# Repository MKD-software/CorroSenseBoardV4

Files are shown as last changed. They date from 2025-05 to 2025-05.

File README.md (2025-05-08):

# CorroSenseBoardV4

This repository contains documentation, Altium design files, and software for the **CorroSenseBoardV4**.

## Jumpers on PCB

Several jumpers must be configured correctly for the board to function as intended. The jumpers are explained below, grouped by the board type.

---

### Motherboard

#### Power Source Configuration

- **P400 (Pin 2 ↔ Pin 3):**  
  Selects the power source as **internal (USB/BAT)** instead of **energy harvesting**.

- **P401 (Pin 1 ↔ Pin 2):**  
  Selects the **battery** as the power source instead of **USB**.

- **P402 (Pin 2 ↔ Pin 3):**  
  Selects the power source as **internal (USB/BAT)** instead of **energy harvesting**.

#### Signal Routing

- **P105 (Pin 1 ↔ Pin 2):**  
  Routes the **DDS signal** to **P104**, the PZT connector on the motherboard.

- **P106 (Pin 1 ↔ Pin 2):**  
  Sends the **PZT output** to the **TIA** on the motherboard.

- **P107:**  
  *(Function not yet documented)*

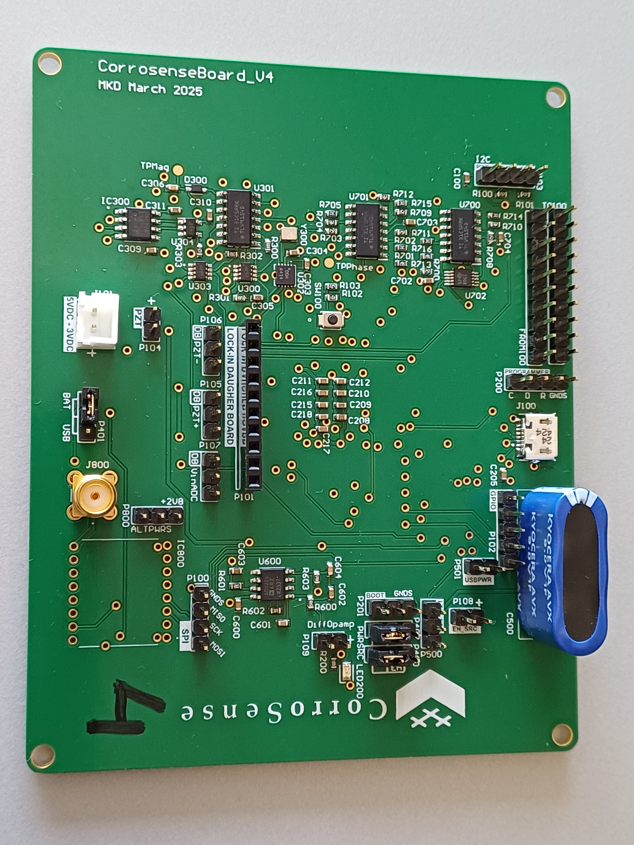
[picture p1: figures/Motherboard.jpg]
Motherboard


---

The board can then be powered on J101 with max 5VDC and min 3VDC.

### Daughterboard

*(Add relevant jumper details here if available)*

## Issues and TODO

#### Motherboard

- The very first ADC reading is always maximum value, doing 1 reading before main loop (and not saving the data) solves the issue.

- Mag and phase measure measurements are identical.

- The DDS gain is highly frequency dependent, above 100kHz the sinewave becomes more like a saw and amplitude of signal decreases. This happens ... could be because of OPAMPS or digital pot.

- Calculate phase and mag, find the right formula, struggling to get correct results, could be due to the VCOMM of 1.4V instead of 0.

- A good measurement is highly dependent on TIA gain and frequency... how to automate it? Maybe make a measurement on the TIA over frequency..?

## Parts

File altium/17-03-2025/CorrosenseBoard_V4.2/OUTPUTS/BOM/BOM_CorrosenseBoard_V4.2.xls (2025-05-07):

 | Component list |  | Bill of Materials for PCB Document [CorrosenseBoardV4_3.PcbDoc]
 | Source Data From: |  | CorrosenseBoardV4_3.PcbDoc
 | Project: |  | CorrosenseBoard_V4.2.PrjPcb
 | Variant: |  | None
 | Report Date: | 17.03.2025 | 10:52
 | Print Date: | 2025-03-17 | 13:52:47
# | Designator | LibRef | Manufacturer | Description | Footprint | MPN | Comment | Quantity
1 | C100 | Cap | Murata Electronics | CAP CER 25V X7R 0603 | 1608[0603] | GCM188R71E224KA55D | 0.22uF | 1
2 | C200, C205, C206, C209, C210, C211, C212, C213, C214, C215, C300, C302, C304, C307, C308, C310, C311, C406, C407, C600, C702, C703, C704, C801 | Cap | Murata Electronics | CAP CER 25V X7R 0603 | 1608[0603] | GCJ188R71E104KA12D | 100nF | 24
3 | C201, C202, C203, C204 | Cap | KYOCERA AVX | CAP CER 25V X7R 0603 | 1608[0603] | 06035A4R3CAT2A | 4.3pF | 4
4 | C207, C216, C217, C400, C403, C504, C505, C506, C507 | Cap | Murata Electronics | CAP CER 25V X7R 0603 | 1608[0603] | GCM188R71E105KA64D | 1uF | 9
5 | C208, C502, C800 | Cap | Murata Electronics | CAP CER 25V X7R 0603 | 1608[0603] | GRM188R61E475KE11J | 4.7uF | 3
6 | C218, C303, C309, C405, C602, C700 | Cap | Murata Electronics | CAP CER 25V X7R 0603 | 1608[0603] | GCJ188R71E103KA01J | 10nF | 6
7 | C301 | Cap | Vishay / Sprague | CAP CER 25V X7R 0603 | 1608[0603] | TR8M106M010C2000 | 10uF Tantalum | 1
8 | C305, C603 | Cap | Murata Electronics | CAP CER 25V X7R 0603 | 1608[0603] | GRM188R71E154KA01D | 150nF | 2
9 | C306, C601, C604 | Cap | KYOCERA AVX | CAP CER 25V X7R 0603 | 1608[0603] | 06033C102KAT2A | 1nF | 3
10 | C401, C402, C404 | Cap | Murata Electronics | CAP CER 25V X7R 0603 | 1608[0603] | GRM188R61E106KA73D | 10uF | 3
11 | C500 | SCMR22L105SRBB0 | Kyocera AVX | Capacitor Polarised | SCMR22L105SRBB0 | SCMR22L105SRBB0 | SCMR22L105SRBB0 | 1
12 | C501 | Cap | Murata Electronics | CAP CER 25V X7R 0603 | 1608[0603] | GRM188C61E226ME01J | 22uF | 1
13 | C503 | Cap | Murata Electronics | CAP CER 25V X7R 0603 | 1608[0603] | GCM188R71E474KA64D | 470nF | 1
14 | C701 | Cap | YAGEO | CAP CER 25V X7R 0603 | 1608[0603] | CC0603KRX7R9BB203 | 20nF | 1
15 | D300 | 1N4148WS | Taiwan Semiconductor | Diode | SOD2513X100N | 1N4148WS | 1N4148WS | 1
16 | FB200, FP400 | BLM21AG121SN1D | Murata Electronics | No Description Available | BEADC2012X105N | BLM21AG121SN1D | BLM21AG121SN1D | 2
17 | FROM100, TO100 | Header 10 | Wurth Elektronik | Header, 10-Pin | HDR1X10 | 61301011121 | Header 10 | 2
18 | IC300 | MAX976ESA+ | Analog Devices | Integrated Circuit | SOIC127P600X175-8N | MAX976ESA+ | MAX976ESA+ | 1
19 | IC400 | ADM7154ACPZ-2.8-R7 | Analog Devices | Integrated Circuit | SON50P300X300X80-9N-D | ADM7154ACPZ-2.8-R7 | ADM7154ACPZ-2.8-R7 | 1
20 | IC401 | MAX6037CAUKADJ+T | Analog Devices | Integrated Circuit | SOT95P280X145-5N | MAX6037CAUKADJ+T | MAX6037CAUKADJ+T | 1
21 | IC500 | EM8500-A001-LF24B | EM Microelectronic-Marin | No Description Available | QFN24_4X4_MAR | EM8500-A001-LF24B+ | EM8500-A001-LF24B | 1
22 | IC800 | RFM98W-433S2 | RF SOLUTIONS | Integrated Circuit | RFM98W433S2 | RFM98W-433S2 | RFM98W-433S2 | 1
23 | J100 | 473460001 | Molex | USB Connectors MICRO USB B RECPT BTTM MOUNT ASSY | Molex_0473460001_0 | 473460001 | 473460001 | 1
24 | J101 | B2B-XH-A | JST Commercial | B2B-XH-A(LF)(SN) | JST_B2B-XH-A | B2B-XH-A(LF)(SN) | B2B-XH-A | 1
25 | J800 | 733910070 | Molex | Connector | 733910070 | 73391-0070 | 733910070 | 1
26 | L500 | Inductor | TAIYO YUDEN | Inductor | C0805 | BRL2012T470M | 47uH | 1
27 | LED200 | 150080RS75000 | Wurth Elektronik | LED | LEDC2012X80N | 150080RS75000 | 150080RS75000 | 1
28 | P100, P103, P200 | Header 4 | Würth Elektronik, Wurth Elektronik | Header, 4-Pin | HDR1X4 | 61300411121 | Header, 4-Pin | 3
29 | P101 | Header 10 | Wurth Elektronik | Header, 10-Pin | HDR1X10 | 61301011821 | Header, 10-Pin FEMALE | 1
30 | P102 | Header 5 | Würth Elektronik | Header, 5-Pin | HDR1X5 | 61300511121 | Header 5 | 1
31 | P104, P108, P109, P501 | Header 2 | Wurth Elektronik | Header, 2-Pin | HDR1X2 | 61300211121 | Header, 2-Pin | 4
32 | P105, P106, P107, P201, P400, P401, P402, P500, P800 | Header 3 | Wurth Elektronik, Mfr.:Wurth Elektronik | Header, 3-Pin | HDR1X3 | 61300311121 | Header, 3-Pin | 9
33 | R100, R101 | Res1 | YAGEO | RES SMD 2% 1.5W 0603, 1608[0603] | 1608[0603] | RC0603FR-072K2L | 2.2K | 2
34 | R102 | Res1 | YAGEO | 1608[0603] | 1608[0603] | AC0603FR-07330RL | 330 | 1
35 | R103 | Res1 | YAGEO | 1608[0603] | 1608[0603] | RC0603FR-07220KL | 220K | 1
36 | R200 | Res1 | YAGEO | 1608[0603] | 1608[0603] | AC0603FR-07150RL | 150 | 1
37 | R201 | Res1 | YAGEO | 1608[0603] | 1608[0603] | RC0603FR-0710RL | 10 | 1
38 | R300, R301 | Res1 | YAGEO | RES SMD 2% 1.5W 0603 | 1608[0603] | AC0603FR-134K99L | 5k | 2
39 | R302, R601 | Res1 | YAGEO | RES SMD 2% 1.5W 0603 | 1608[0603] | RC0603FR-071KL | 1k | 2
40 | R303 | Res1 | YAGEO | RES SMD 2% 1.5W 0603 | 1608[0603] | AC0603FR-1012KL | 12k | 1
41 | R400, R402 | Res1 |  | RES SMD 2% 1.5W 0603 | 1608[0603] |  |  | 2
42 | R401 | Res1 | YAGEO | RES SMD 2% 1.5W 0603 | 1608[0603] | AC0603FR-07150KL | 150k | 1
43 | R403 | Res1 | YAGEO | RES SMD 2% 1.5W 0603 | 1608[0603] | AC0603FR-07820KL | 820k | 1
44 | R600, R603 | Res1 | YAGEO | RES SMD 2% 1.5W 0603 | 1608[0603] | AF0603FR-074K02L | 4.02K | 2
45 | R602 | Res1 | YAGEO | RES SMD 2% 1.5W 0603 | 1608[0603] | AC0603FR-0749K9L | 49.9K | 1
46 | R700, R703, R708, R709, R711 | Res1 | YAGEO | RES SMD 2% 1.5W 0603 | 1608[0603] | AC0603FR-072K4L | 2.4k | 5
47 | R701, R704, R710, R712, R713 | Res1 | YAGEO | RES SMD 2% 1.5W 0603 | 1608[0603] | RC0603FR-075K6L | 5.6k | 5
48 | R702, R705, R707, R714, R715, R716 | Res1 | YAGEO | RES SMD 2% 1.5W 0603 | 1608[0603] | RC0603FR-0710KL | 10k | 6
49 | R706 | Res1 | YAGEO | RES SMD 2% 1.5W 0603 | 1608[0603] | AC0603FR-076K2L | 6.2k | 1
50 | SW100 | B3U-1000P-B | Omron Electronics | No Description Available | B3U-1000P-B | B3U-1000P-B | B3U-1000P-B | 1
51 | U200 | STM32L451VCT6 | STMicroelectronics | No Description Available | LQFP100-14x14mm_STM | STM32L451VCT6 | STM32L451VCT6 | 1
52 | U201 | CP2102-GMR | Silicon Labs | No Description Available | QFN50P500X500X100-29N-D | CP2102-GMR | CP2102-GMR | 1
53 | U300, U303 | TPL0501-100DCNR | Texas Instruments | 256-Taps, 100k, Single-Channel Potentiometer With SPI Interface 8-SOT-23 -40 to 125 | SOT65P280X145-8N | TPL0501-100DCNR | TPL0501-100DCNR | 2
54 | U301, U700, U701 | TLV2444CD | Texas Instruments | No Description Available | SOIC127P600X175-14N | TLV9154IDR | TLV9154IDR | 3
55 | U302 | AD9837ACPZ-RL7 | Analog Devices | No Description Available | CP_10_9_ADI | AD9837BCPZ-RL7 | AD9837BCPZ-RL7 | 1
56 | U304 | SN74AHC1G86DBVR | Texas Instruments | No Description Available | SOT95P280X145-5N | SN74AHC1G86DBVR | SN74AHC1G86DBVR | 1
57 | U600 | AD8226ARZ | Analog Devices Inc | No Description Available | SOIC127P600X175-8N | AD8226ARZ | AD8226ARZ | 1
58 | U702 | ADS1115IDGST | Texas Instruments |  | SOP50P490X110-10N | ADS1115IDGST | ADS1115IDGST | 1
59 | Y200 | ABS07-166-32.768KHZ-T | Abracon LLC | 32.768 kHz Â±10ppm Crystal 7pF 70 kOhms 2-SMD, No Lead | XTAL_ABS07-166-32.768KHZ-T | ABS07-166-32.768KHZ-T | ABS07-166-32.768KHZ-T | 1
60 | Y201 | ABM3-8.000MHZ-D2Y-T | Abracon | No Description Available | XTAL_ABM3-8.000MHZ-D2Y-T | ABM3-8.000MHZ-D2Y-T | ABM3-8.000MHZ-D2Y-T | 1
61 | Y300 | SG-210STF_16.0000ML0 | Epson Timing | Crystal or Oscillator | SG210STF160000ML0 | SG-210STF 16.0000ML0 | SG-210STF_16.0000ML0 | 1
Approved |  |  | Notes |  |  |  |  | 143

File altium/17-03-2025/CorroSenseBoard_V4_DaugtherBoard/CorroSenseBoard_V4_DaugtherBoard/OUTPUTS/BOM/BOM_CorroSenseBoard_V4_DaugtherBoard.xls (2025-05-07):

 | Component list |  | Bill of Materials for BOM Document [CorroSenseBoard_V4_DaugtherBoard.BomDoc]
 | Source Data From: |  | CorroSenseBoard_V4_DaugtherBoard.BomDoc
 | Project: |  | CorroSenseBoard_V4_DaugtherBoard.PrjPcb
 | Variant: |  | None
 | Report Date: | 14.03.2025 | 15:42
 | Print Date: | 2025-03-17 | 13:53:42
# | Designator | LibRef | Manufacturer | Description | Footprint | MPN | Name | Quantity
1 | C200, C300, C301, C302, C318, C319, C320, C321, C322, C323, C324, C325 | Cap | Murata Electronics | CAP CER 25V X7R 0603 | 1608[0603] | GCJ188R71E104KA12D | 100nF | 12
2 | C201 | Cap | KYOCERA AVX | CAP CER 25V X7R 0603 | 1608[0603] | 06033C101KAT2A | 100pF | 1
3 | C202, C204, C303, C305, C309, C311, C313, C317 | Cap | Murata Electronics | CAP CER 25V X7R 0603 | 1608[0603] | GCM188R71E105KA64D | 1uF | 8
4 | C203 | Cap | Murata Electronics | CAP CER 25V X7R 0603 | 1608[0603] | GRM188R61E475KE11J | 4.7uF | 1
5 | C205 | Cap | Murata Electronics | CAP CER 25V X7R 0603 | 1608[0603] | GRM1885C1H4R7WA01D | 4.7pF | 1
6 | C304, C306, C307, C312, C314, C315 | Cap | KYOCERA AVX | CAP CER 25V X7R 0603 | 1608[0603] | 06033C102KAT2A | 1nF | 6
7 | C308, C310, C316 | Cap | Murata Electronics | CAP CER 25V X7R 0603 | 1608[0603] | GRM188R71E154KA01D | 150nF | 3
8 | D200, D201, D202 | ZHCS400TA | Diodes Incorporated | Diode | SOD2513X120N | ZHCS400TA | ZHCS400TA | 3
9 | L200, L201 | Inductor | Murata Electronics | FIXED IND 4.7UH 620MA 550MOHM SM | 6-0805_N | LQM18PN4R7MFRL | LQM18PN4R7MFRL | 2
10 | P100, P102, P200, P201 | Header 2 | Wurth Elektronik | Header, 2-Pin | HDR1X2 | 61300211121 | Header, 2-Pin | 4
11 | P101 | Header 10 | Wurth Elektronik | Header, 10-Pin | HDR1X10 | 61301011121 | Header, 10-Pin | 1
12 | R200 | Res1 | YAGEO | RES SMD 2% 1.5W 0603 | 1608[0603] | AC0603FR-07270KL | 270K | 1
13 | R201 | Res1 | YAGEO | RES SMD 2% 1.5W 0603 | 1608[0603] | RC0603FR-07100KL | 100K | 1
14 | R202 | Res1 | YAGEO | RES SMD 2% 1.5W 0603 | 1608[0603] | AC0603FR-10110KL | 110K | 1
15 | R203 | Res1 | YAGEO | RES SMD 2% 1.5W 0603 | 1608[0603] | AC0603FR-07330KL | 330K | 1
16 | R300 | Res1 | YAGEO | RES SMD 2% 1.5W 0603 | 1608[0603] | RC0603FR-071KL | 1K | 1
17 | R301 | Res1 | YAGEO | RES SMD 2% 1.5W 0603 | 1608[0603] | AC0603FR-072KL | 2K | 1
18 | R302, R304, R305, R308, R309, R310, R314, R316, R317, R320, R321, R322 | Res1 | YAGEO | RES SMD 2% 1.5W 0603 | 1608[0603] | RC0603FR-0710KL | 10K | 12
19 | R303, R311, R313, R315 | Res1 | YAGEO | RES SMD 2% 1.5W 0603 | 1608[0603] | AC0603FR-134K99L | 5k | 4
20 | R306 | Res1 | YAGEO | RES SMD 2% 1.5W 0603 | 1608[0603] | AC0603FR-0762RL | 62 | 1
21 | R307 | Res1 | YAGEO | RES SMD 2% 1.5W 0603 | 1608[0603] | RC0603FR-07470RL | 470 | 1
22 | R312 | Res1 | YAGEO | RES SMD 2% 1.5W 0603 | 1608[0603] | RC0603FR-106K8L | 6.8K | 1
23 | R318 | Res1 | YAGEO | RES SMD 2% 1.5W 0603 | 1608[0603] | RC0603FR-10220RL | 220 | 1
24 | R319 | Res1 | YAGEO | RES SMD 2% 1.5W 0603 | 1608[0603] | RC0603FR-07910RL | 910 | 1
25 | U200 | LT1945EMSPBF | Analog Devices Inc | No Description Available | MSOP-10_MS_LIT | LT1945EMSPBF | LT1945EMSPBF | 1
26 | U300 | MAX5438EUB+ | Analog Devices / Maxim Integrated |  | SOP50P490X110-10N | MAX5438EUB+ | MAX5438EUB+ | 1
27 | U301, U303 | TLV2444CD | Texas Instruments | No Description Available | SOIC127P600X175-14N | TLV9154IDR | TLV9154IDR | 2
28 | U302, U304 | ADI-AD630-RW-20 | Analog Devices | Consumer Circuit, PDSO20 | SOIC127P1032X265-20N | AD630ARZ | AD630ARZ | 2
Approved |  |  | Notes |  |  |  |  | 75

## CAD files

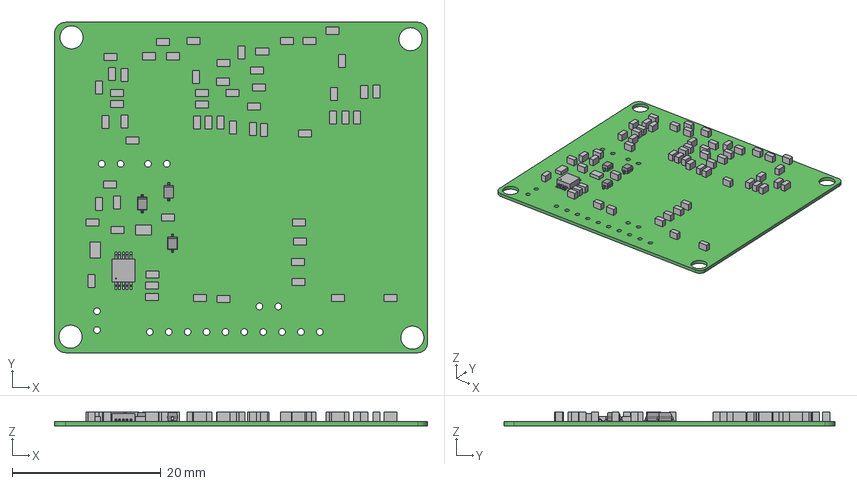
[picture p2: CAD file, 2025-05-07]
altium/17-03-2025/CorroSenseBoard_V4_DaugtherBoard/CorroSenseBoard_V4_DaugtherBoard/OUTPUTS/3D/CorroSenseBoard_V4_DaugtherBoard.step
50.2 x 44.5 x 1.92 mm
Extruded x 61
FilletPinL x 3
FilletPinR x 3

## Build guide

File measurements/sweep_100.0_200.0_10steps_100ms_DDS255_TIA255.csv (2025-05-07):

Frequency [Hz] | Magnitude | Phase [°]
100000 | 0.030518509475997192 | 4212900.0
111111 | 0.04689551678859501 | 2741657.142857143
122222 | 0.03321486697445777 | 3870900.0
133333 | 0.03385125757421888 | 3798128.5714285714
144444 | 0.035143208574942894 | 3658500.0
155555 | 0.03673229503379371 | 3500228.5714285714
166666 | 0.040110705547310575 | 3205414.285714286
177777 | 0.04675081813931744 | 2750142.8571428573
188888 | 0.04594532506317482 | 2798357.1428571427
199999 | 0.04507956543298922 | 2852100.0000000005

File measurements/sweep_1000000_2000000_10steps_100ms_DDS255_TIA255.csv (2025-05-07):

Frequency [Hz] | Magnitude | Phase [°]
100000 | 0.030518509475997192 | 4212900.0
111111 | 0.04688452341881945 | 2742300.0
122222 | 0.03320935175345377 | 3871542.8571428573
133333 | 0.033855841825506994 | 3797614.285714286
144444 | 0.03513950383020592 | 3658885.7142857146
155555 | 0.03672015569346014 | 3501385.7142857146
166666 | 0.04012358062833527 | 3204385.7142857146
177777 | 0.04671587405400355 | 2752200.0000000005
188888 | 0.04595165885488466 | 2797971.4285714286
199999 | 0.04508363013389838 | 2851842.8571428573

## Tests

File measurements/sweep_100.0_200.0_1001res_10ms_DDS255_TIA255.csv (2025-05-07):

Frequency [Hz] | Magnitude | Phase [°]
100000 | 0.030518509475997192 | 4212900.0
100100 | 0.04694394892498357 | 2738828.571428572
100200 | 0.030518509475997192 | 4212900.0
100300 | 0.033627009213800525 | 3823457.142857143
100400 | 0.03341240936883959 | 3848014.2857142864
100500 | 0.03356605800214823 | 3830400.0
100600 | 0.033549166303217366 | 3832328.5714285714
100700 | 0.03352105122016626 | 3835542.8571428577
100800 | 0.0335042047776996 | 3837471.428571429
100900 | 0.03347840642785403 | 3840428.571428572
101001 | 0.033448172057397065 | 3843900.0
101101 | 0.03341910904655282 | 3847242.8571428577
101201 | 0.033399018068868774 | 3849557.1428571427
101301 | 0.03337226764558652 | 3852642.8571428573
101401 | 0.03334444814938313 | 3855857.1428571427
101501 | 0.03332111559094998 | 3858557.142857143
101601 | 0.033297815663292485 | 3861257.142857143
101701 | 0.033276762836511264 | 3863700.0
101801 | 0.03324910227423859 | 3866914.2857142864
101901 | 0.03322479898996611 | 3869742.8571428577
102002 | 0.0332016335203692 | 3872442.8571428573
102102 | 0.03318070210365651 | 3874885.7142857146
102202 | 0.033158697526361164 | 3877457.142857143
102302 | 0.033140016570008285 | 3879642.8571428573
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

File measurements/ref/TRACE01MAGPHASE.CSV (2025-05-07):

!Keysight Technologies | E4990A | MY54302532 | A.03.02
!Date: Wed May 07 10:40:29 2025
BEGIN CH1_DATA
Frequency(Hz) | |Z|(Ohm)-data | theta-z(deg)-data
+5.00000000000e+004 | +1.27921414392e+003 | -8.87571191121e+001
+5.00650250000e+004 | +1.27763299996e+003 | -8.87618906651e+001
+5.01301340000e+004 | +1.27597657355e+003 | -8.87710836920e+001
+5.01953280000e+004 | +1.27412923572e+003 | -8.87730096643e+001
+5.02606070000e+004 | +1.27236761422e+003 | -8.87731828333e+001
+5.03259710000e+004 | +1.27061033431e+003 | -8.87701985494e+001
+5.03914190000e+004 | +1.26886069958e+003 | -8.87635472113e+001
+5.04569530000e+004 | +1.26730949295e+003 | -8.87552114678e+001
+5.05225720000e+004 | +1.26587712046e+003 | -8.87541621611e+001
+5.05882770000e+004 | +1.26437124268e+003 | -8.87657274664e+001
+5.06540670000e+004 | +1.26256444609e+003 | -8.87741318947e+001
+5.07199420000e+004 | +1.26082747170e+003 | -8.87751426842e+001
+5.07859030000e+004 | +1.25911612554e+003 | -8.87757197615e+001
+5.08519500000e+004 | +1.25738101540e+003 | -8.87745714014e+001
+5.09180830000e+004 | +1.25568918543e+003 | -8.87747700130e+001
+5.09843010000e+004 | +1.25394654802e+003 | -8.87742462159e+001
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

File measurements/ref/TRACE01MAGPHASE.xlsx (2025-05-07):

!Keysight Technologies,E4990A,MY54302532,A.03.02
!Date: Wed May 07 10:40:29 2025
BEGIN CH1_DATA
Frequency(Hz), |Z|(Ohm)-data, theta-z(deg)-data
+5.00000000000e+004, +1.27921414392e+003, -8.87571191121e+001
+5.00650250000e+004, +1.27763299996e+003, -8.87618906651e+001
+5.01301340000e+004, +1.27597657355e+003, -8.87710836920e+001
+5.01953280000e+004, +1.27412923572e+003, -8.87730096643e+001
+5.02606070000e+004, +1.27236761422e+003, -8.87731828333e+001
+5.03259710000e+004, +1.27061033431e+003, -8.87701985494e+001
+5.03914190000e+004, +1.26886069958e+003, -8.87635472113e+001
+5.04569530000e+004, +1.26730949295e+003, -8.87552114678e+001
+5.05225720000e+004, +1.26587712046e+003, -8.87541621611e+001
+5.05882770000e+004, +1.26437124268e+003, -8.87657274664e+001
+5.06540670000e+004, +1.26256444609e+003, -8.87741318947e+001
+5.07199420000e+004, +1.26082747170e+003, -8.87751426842e+001
+5.07859030000e+004, +1.25911612554e+003, -8.87757197615e+001
+5.08519500000e+004, +1.25738101540e+003, -8.87745714014e+001
+5.09180830000e+004, +1.25568918543e+003, -8.87747700130e+001
+5.09843010000e+004, +1.25394654802e+003, -8.87742462159e+001
+5.10506060000e+004, +1.25226596191e+003, -8.87737587742e+001
+5.11169970000e+004, +1.25058373141e+003, -8.87719392860e+001
+5.11834750000e+004, +1.24889922433e+003, -8.87711525301e+001
+5.12500390000e+004, +1.24727995219e+003, -8.87688452521e+001
+5.13166890000e+004, +1.24565727264e+003, -8.87661745437e+001
+5.13834260000e+004, +1.24399903517e+003, -8.87687032875e+001
+5.14502500000e+004, +1.24231290944e+003, -8.87691161406e+001
+5.15171610000e+004, +1.24067707529e+003, -8.87686891910e+001
+5.15841590000e+004, +1.23900039417e+003, -8.87681721908e+001
+5.16512440000e+004, +1.23731603456e+003, -8.87687813740e+001
+5.17184160000e+004, +1.23567092807e+003, -8.87663934711e+001
+5.17856760000e+004, +1.23395150941e+003, -8.87630444519e+001
+5.18530230000e+004, +1.23230791823e+003, -8.87600762868e+001
+5.19204570000e+004, +1.23073459956e+003, -8.87523081633e+001
+5.19879800000e+004, +1.22929195935e+003, -8.87516960308e+001
+5.20555900000e+004, +1.22773667616e+003, -8.87568260229e+001
+5.21232880000e+004, +1.22607381168e+003, -8.87606684108e+001
+5.21910740000e+004, +1.22438236107e+003, -8.87601906121e+001
+5.22589480000e+004, +1.22274618103e+003, -8.87615896127e+001
+5.23269110000e+004, +1.22112985040e+003, -8.87607417443e+001
+5.23949620000e+004, +1.21950464679e+003, -8.87606525434e+001
+5.24631010000e+004, +1.21782528927e+003, -8.87602891818e+001
+5.25313290000e+004, +1.21620805296e+003, -8.87606744719e+001
+5.25996460000e+004, +1.21461512804e+003, -8.87589456055e+001
+5.26680520000e+004, +1.21294661325e+003, -8.87580661848e+001
+5.27365460000e+004, +1.21136598932e+003, -8.87564959053e+001
+5.28051300000e+004, +1.20973801214e+003, -8.87577649014e+001
+5.28738030000e+004, +1.20805665922e+003, -8.87570594904e+001
+5.29425650000e+004, +1.20643422705e+003, -8.87556207257e+001
+5.30114170000e+004, +1.20478703389e+003, -8.87501683762e+001
+5.30803580000e+004, +1.20319532915e+003, -8.87464056601e+001
+5.31493890000e+004, +1.20165972320e+003, -8.87425859773e+001
+5.32185090000e+004, +1.20002273805e+003, -8.87376339464e+001
+5.32877200000e+004, +1.19860378310e+003, -8.87308467263e+001
+5.33570200000e+004, +1.19730075346e+003, -8.87346042093e+001
+5.34264110000e+004, +1.19568781425e+003, -8.87480343411e+001
+5.34958910000e+004, +1.19402086902e+003, -8.87532186453e+001
+5.35654630000e+004, +1.19229225238e+003, -8.87548774843e+001
+5.36351240000e+004, +1.19063560002e+003, -8.87530500240e+001
+5.37048770000e+004, +1.18895946756e+003, -8.87503335358e+001
+5.37747200000e+004, +1.18733991957e+003, -8.87464196950e+001
+5.38446530000e+004, +1.18568628288e+003, -8.87432883149e+001
+5.39146780000e+004, +1.18404567301e+003, -8.87415336159e+001
+5.39847940000e+004, +1.18236391996e+003, -8.87327557190e+001
+5.40550010000e+004, +1.18079075784e+003, -8.87196410276e+001
+5.41252990000e+004, +1.17935228496e+003, -8.87041151846e+001
+5.41956890000e+004, +1.17816166274e+003, -8.86979532702e+001
+5.42661700000e+004, +1.17699770241e+003, -8.87011264235e+001
+5.43367430000e+004, +1.17561896980e+003, -8.87208578727e+001
+5.44074080000e+004, +1.17388694355e+003, -8.87314923851e+001
+5.44781640000e+004, +1.17223532219e+003, -8.87308232925e+001
+5.45490130000e+004, +1.17071936042e+003, -8.87302489228e+001
+5.46199540000e+004, +1.16918160194e+003, -8.87386959392e+001
+5.46909870000e+004, +1.16746126411e+003, -8.87448465278e+001
+5.47621120000e+004, +1.16576206784e+003, -8.87415495014e+001
+5.48333300000e+004, +1.16409985003e+003, -8.87408891318e+001
+5.49046410000e+004, +1.16246427902e+003, -8.87377561103e+001
+5.49760440000e+004, +1.16080515369e+003, -8.87352824400e+001
+5.50475400000e+004, +1.15913740112e+003, -8.87271436968e+001
+5.51191290000e+004, +1.15747108560e+003, -8.87156221396e+001
+5.51908110000e+004, +1.15599336118e+003, -8.86965913111e+001
+5.52625870000e+004, +1.15485064618e+003, -8.86805480708e+001
+5.53344560000e+004, +1.15377770370e+003, -8.86808334226e+001
+5.54064180000e+004, +1.15257468677e+003, -8.86988036896e+001
+5.54784740000e+004, +1.15093415832e+003, -8.87215242238e+001
+5.55506230000e+004, +1.14913131130e+003, -8.87253790174e+001
+5.56228660000e+004, +1.14740601341e+003, -8.87241431349e+001
+5.56952040000e+004, +1.14569525897e+003, -8.87178967029e+001
+5.57676350000e+004, +1.14410881501e+003, -8.87040913295e+001
+5.58401610000e+004, +1.14276314075e+003, -8.86928600222e+001
+5.59127810000e+004, +1.14142143384e+003, -8.87000146188e+001
+5.59854950000e+004, +1.13963524959e+003, -8.87028650957e+001
+5.60583040000e+004, +1.13791415946e+003, -8.86836832047e+001
+5.61312070000e+004, +1.13643609826e+003, -8.86525935264e+001
+5.62042060000e+004, +1.13568420264e+003, -8.86225086908e+001
+5.62772990000e+004, +1.13533869222e+003, -8.86399903713e+001
+5.63504880000e+004, +1.13400308268e+003, -8.86899595285e+001
+5.64237710000e+004, +1.13218890711e+003, -8.87110597392e+001
+5.64971500000e+004, +1.13044746819e+003, -8.87152676136e+001
+5.65706240000e+004, +1.12889279426e+003, -8.87179015701e+001
+5.66441940000e+004, +1.12730792104e+003, -8.87231165436e+001
+5.67178600000e+004, +1.12573689201e+003, -8.87253646529e+001
+5.67916210000e+004, +1.12417895343e+003, -8.87275549570e+001
+5.68654780000e+004, +1.12263595984e+003, -8.87287274247e+001
+5.69394320000e+004, +1.12109202967e+003, -8.87319932930e+001
+5.70134810000e+004, +1.11949288099e+003, -8.87321703789e+001
+5.70876270000e+004, +1.11799480605e+003, -8.87309817047e+001
+5.71618690000e+004, +1.11650499772e+003, -8.87335705448e+001
+5.72362080000e+004, +1.11492691759e+003, -8.87374157063e+001
+5.73106430000e+004, +1.11333560898e+003, -8.87370207673e+001
+5.73851760000e+004, +1.11177393215e+003, -8.87360790470e+001
+5.74598050000e+004, +1.11022688252e+003, -8.87333763334e+001
+5.75345310000e+004, +1.10872563153e+003, -8.87300007526e+001
+5.76093550000e+004, +1.10720868610e+003, -8.87295131668e+001
+5.76842750000e+004, +1.10572476423e+003, -8.87277443964e+001
+5.77592930000e+004, +1.10424333230e+003, -8.87246435216e+001
+5.78344090000e+004, +1.10276081290e+003, -8.87238657124e+001
+5.79096230000e+004, +1.10128061582e+003, -8.87231783099e+001
+5.79849340000e+004, +1.09973789120e+003, -8.87239814654e+001
+5.80603430000e+004, +1.09821529700e+003, -8.87201145637e+001
+5.81358500000e+004, +1.09671989803e+003, -8.87147145972e+001
+5.82114560000e+004, +1.09529593162e+003, -8.87095414665e+001
+5.82871590000e+004, +1.09387544196e+003, -8.87093392001e+001
+5.83629620000e+004, +1.09237401814e+003, -8.87111385889e+001
+5.84388620000e+004, +1.09079098822e+003, -8.87061405324e+001
+5.85148620000e+004, +1.08929708080e+003, -8.86954682860e+001
+5.85909600000e+004, +1.08796726059e+003, -8.86803465759e+001
+5.86671580000e+004, +1.08683553801e+003, -8.86721980776e+001
+5.87434540000e+004, +1.08570967646e+003, -8.86748110458e+001
+5.88198500000e+004, +1.08449789472e+003, -8.86847203786e+001
+5.88963450000e+004, +1.08310809647e+003, -8.87046131290e+001
+5.89729390000e+004, +1.08146645648e+003, -8.87150384949e+001
+5.90496330000e+004, +1.07988686169e+003, -8.87158135304e+001
+5.91264270000e+004, +1.07835665078e+003, -8.87136538746e+001
+5.92033210000e+004, +1.07686847206e+003, -8.87128603782e+001
+5.92803140000e+004, +1.07541283968e+003, -8.87128088337e+001
+5.93574080000e+004, +1.07390177182e+003, -8.87133768756e+001
+5.94346020000e+004, +1.07242011844e+003, -8.87106488151e+001
+5.95118970000e+004, +1.07095346959e+003, -8.87073070345e+001
+5.95892920000e+004, +1.06955845282e+003, -8.87022533515e+001
+5.96667870000e+004, +1.06824813130e+003, -8.87015455248e+001
+5.97443840000e+004, +1.06687711118e+003, -8.87075740684e+001
+5.98220810000e+004, +1.06537426030e+003, -8.87133925525e+001
+5.98998790000e+004, +1.06383521903e+003, -8.87133565868e+001
+5.99777790000e+004, +1.06232648920e+003, -8.87138484663e+001
+6.00557800000e+004, +1.06084818183e+003, -8.87074498396e+001
+6.01338820000e+004, +1.05940910273e+003, -8.87039877235e+001
+6.02120860000e+004, +1.05802176949e+003, -8.86977542387e+001
+6.02903910000e+004, +1.05672850532e+003, -8.86957925526e+001
+6.03687990000e+004, +1.05539904219e+003, -8.87010916185e+001
+6.04473080000e+004, +1.05391884480e+003, -8.87081983384e+001
+6.05259200000e+004, +1.05243681082e+003, -8.87058523462e+001
+6.06046330000e+004, +1.05098864136e+003, -8.87037530421e+001
+6.06834490000e+004, +1.04954166947e+003, -8.87058464788e+001
+6.07623680000e+004, +1.04798862352e+003, -8.87063072005e+001
+6.08413890000e+004, +1.04641873005e+003, -8.87020543882e+001
+6.09205130000e+004, +1.04491262583e+003, -8.86916140962e+001
+6.09997400000e+004, +1.04340994023e+003, -8.86736973027e+001
+6.10790700000e+004, +1.04215665364e+003, -8.86532455199e+001
+6.11585030000e+004, +1.04123711126e+003, -8.86369201435e+001
+6.12380390000e+004, +1.04040539131e+003, -8.86525218492e+001
+6.13176790000e+004, +1.03899605132e+003, -8.86787095582e+001
+6.13974230000e+004, +1.03745199303e+003, -8.86838168423e+001
+6.14772700000e+004, +1.03597551217e+003, -8.86839001475e+001
+6.15572210000e+004, +1.03460464071e+003, -8.86834875350e+001
+6.16372760000e+004, +1.03322229599e+003, -8.86875029781e+001
+6.17174350000e+004, +1.03183607608e+003, -8.86917236615e+001
+6.17976980000e+004, +1.03042105449e+003, -8.86945525767e+001
+6.18780660000e+004, +1.02893020565e+003, -8.86962935399e+001
+6.19585380000e+004, +1.02750614854e+003, -8.86952578530e+001
+6.20391150000e+004, +1.02606816562e+003, -8.86940389515e+001
+6.21197960000e+004, +1.02462626411e+003, -8.86923662892e+001
+6.22005830000e+004, +1.02322896694e+003, -8.86894695908e+001
+6.22814740000e+004, +1.02186395236e+003, -8.86864186618e+001
+6.23624710000e+004, +1.02048444459e+003, -8.86866673326e+001
+6.24435730000e+004, +1.01910536167e+003, -8.86836059284e+001
+6.25247810000e+004, +1.01774535630e+003, -8.86828677803e+001
+6.26060940000e+004, +1.01643036980e+003, -8.86815928321e+001
+6.26875130000e+004, +1.01511192103e+003, -8.86804732910e+001
+6.27690380000e+004, +1.01375794810e+003, -8.86850440126e+001
+6.28506690000e+004, +1.01235280818e+003, -8.86871785365e+001
+6.29324060000e+004, +1.01093479186e+003, -8.86888794037e+001
+6.30142490000e+004, +1.00951908745e+003, -8.86892937467e+001
+6.30961990000e+004, +1.00808625196e+003, -8.86887232397e+001
+6.31782550000e+004, +1.00665680427e+003, -8.86858484784e+001
+6.32604180000e+004, +1.00523954744e+003, -8.86805240527e+001
+6.33426880000e+004, +1.00392106509e+003, -8.86742527936e+001
+6.34250650000e+004, +1.00263768446e+003, -8.86723286537e+001
+6.35075490000e+004, +1.00131857614e+003, -8.86703081703e+001
+6.35901400000e+004, +1.00002171946e+003, -8.86713286422e+001
+6.36728390000e+004, +9.98736184797e+002, -8.86755441968e+001
+6.37556450000e+004, +9.97320795236e+002, -8.86794813860e+001
+6.38385590000e+004, +9.95922738407e+002, -8.86809951044e+001
+6.39215810000e+004, +9.94514095893e+002, -8.86815407180e+001
+6.40047110000e+004, +9.93106607508e+002, -8.86801243159e+001
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

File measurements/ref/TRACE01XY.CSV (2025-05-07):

!Keysight Technologies | E4990A | MY54302532 | A.03.02
!Date: Wed May 07 10:40:02 2025
BEGIN CH1_DATA
Frequency(Hz) | R(Ohm)-data | X(Ohm)-data
+5.00000000000e+004 | +2.78124120107e+001 | -1.27884954774e+003
+5.00650250000e+004 | +2.76405998839e+001 | -1.27725237373e+003
+5.01301340000e+004 | +2.74427896021e+001 | -1.27553436811e+003
+5.01953280000e+004 | +2.73588512476e+001 | -1.27374460447e+003
+5.02606070000e+004 | +2.73225284025e+001 | -1.27193359160e+003
+5.03259710000e+004 | +2.73423506424e+001 | -1.27017745589e+003
+5.03914190000e+004 | +2.74452933158e+001 | -1.26844525173e+003
+5.04569530000e+004 | +2.75490468796e+001 | -1.26689224309e+003
+5.05225720000e+004 | +2.75779079120e+001 | -1.26545101691e+003
+5.05882770000e+004 | +2.72837199228e+001 | -1.26393074552e+003
+5.06540670000e+004 | +2.70632750997e+001 | -1.26217823459e+003
+5.07199420000e+004 | +2.69809898083e+001 | -1.26039255287e+003
+5.07859030000e+004 | +2.69522299868e+001 | -1.25869384255e+003
+5.08519500000e+004 | +2.69152299539e+001 | -1.25695294092e+003
+5.09180830000e+004 | +2.69210081199e+001 | -1.25528265790e+003
+5.09843010000e+004 | +2.68682084250e+001 | -1.25355115300e+003
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

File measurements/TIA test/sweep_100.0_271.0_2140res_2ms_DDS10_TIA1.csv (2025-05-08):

Frequency [Hz] | Magnitude | Phase [°]
100000 | 32767 | 32767
100214 | 22328 | 22328
100428 | 22323 | 22323
100642 | 22323 | 22323
100856 | 22327 | 22327
101070 | 22328 | 22328
101284 | 22325 | 22325
101498 | 22330 | 22330
101712 | 22322 | 22322
101926 | 22319 | 22319
102140 | 22313 | 22313
102354 | 22316 | 22316
102568 | 22309 | 22309
102782 | 22297 | 22297
102996 | 22298 | 22298
103210 | 22312 | 22312
103424 | 22383 | 22383
103638 | 22288 | 22288
103852 | 22296 | 22296
104066 | 22351 | 22351
104280 | 22302 | 22302
104494 | 22309 | 22309
104708 | 22303 | 22303
104922 | 22306 | 22306
105136 | 22314 | 22314
105350 | 22503 | 22503
105564 | 22321 | 22321
105778 | 22325 | 22325
105992 | 22347 | 22347
106206 | 22338 | 22338
106420 | 22339 | 22339
106634 | 22338 | 22338
106848 | 22381 | 22381
107062 | 22370 | 22370
107276 | 22353 | 22353
107490 | 22364 | 22364
107704 | 22369 | 22369
107918 | 22369 | 22369
108132 | 23716 | 23716
108346 | 22370 | 22370
108560 | 22357 | 22357
108774 | 22352 | 22352
108988 | 22351 | 22351
109202 | 22345 | 22345
109416 | 22347 | 22347
109630 | 22351 | 22351
109844 | 22345 | 22345
110058 | 22348 | 22348
110272 | 22356 | 22356
110486 | 22361 | 22361
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

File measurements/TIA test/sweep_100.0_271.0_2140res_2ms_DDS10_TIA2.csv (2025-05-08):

Frequency [Hz] | Magnitude | Phase [°]
100000 | 32767 | 32767
100214 | 21715 | 21715
100428 | 29674 | 29674
100642 | 27257 | 27257
100856 | 26929 | 26929
101070 | 26977 | 26977
101284 | 27055 | 27055
101498 | 27617 | 27617
101712 | 27086 | 27086
101926 | 27132 | 27132
102140 | 27170 | 27170
102354 | 27230 | 27230
102568 | 27285 | 27285
102782 | 27338 | 27338
102996 | 27396 | 27396
103210 | 27707 | 27707
103424 | 27460 | 27460
103638 | 27497 | 27497
103852 | 27515 | 27515
104066 | 27505 | 27505
104280 | 29620 | 29620
104494 | 27362 | 27362
104708 | 32767 | 32767
104922 | 32767 | 32767
105136 | 32767 | 32767
105350 | 31614 | 31614
105564 | 32767 | 32767
105778 | 32767 | 32767
105992 | 27539 | 27539
106206 | 32767 | 32767
106420 | 32767 | 32767
106634 | 32767 | 32767
106848 | 32767 | 32767
107062 | 32767 | 32767
107276 | 32767 | 32767
107490 | 31223 | 31223
107704 | 32767 | 32767
107918 | 28098 | 28098
108132 | 32767 | 32767
108346 | 32767 | 32767
108560 | 32767 | 32767
108774 | 32767 | 32767
108988 | 32767 | 32767
109202 | 32767 | 32767
109416 | 32767 | 32767
109630 | 32390 | 32390
109844 | 32151 | 32151
110058 | 27589 | 27589
110272 | 27628 | 27628
110486 | 27791 | 27791
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

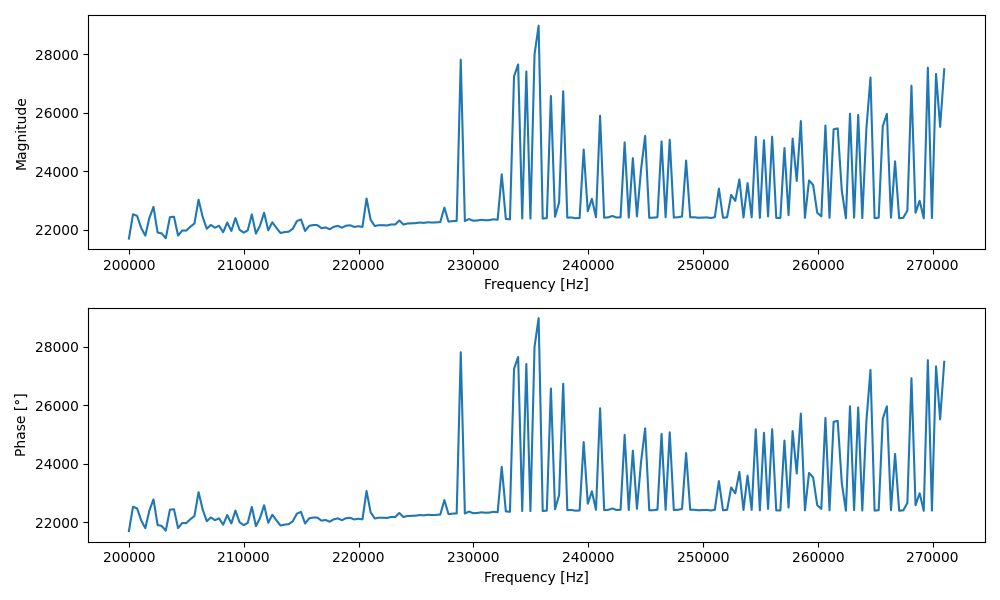
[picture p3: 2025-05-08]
measurements/TIA test/sweep_200.0_271.0_3568res_2ms_DDS10_TIA4.png

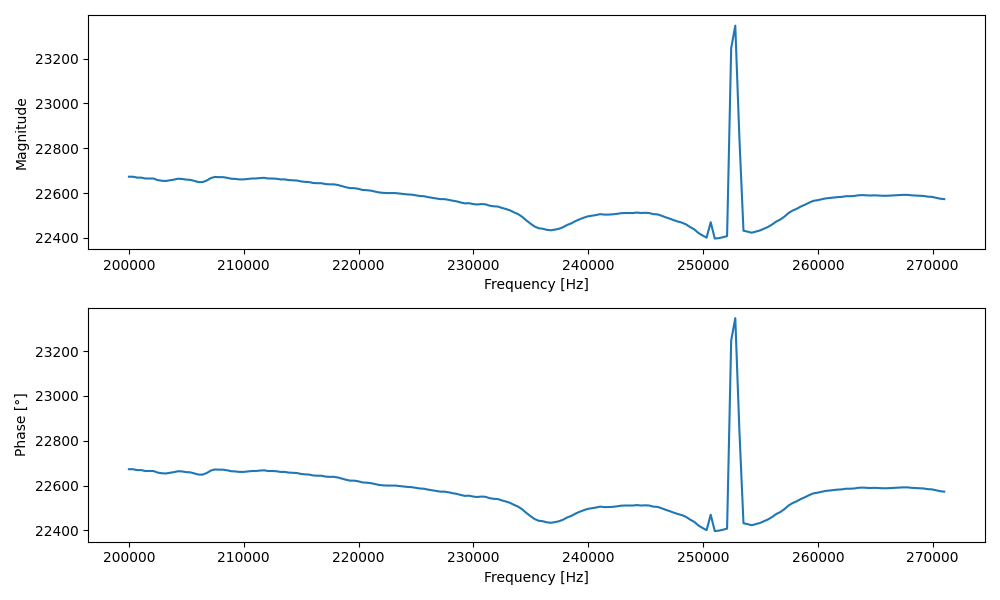
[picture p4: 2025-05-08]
measurements/TIA test/sweep_200.0_271.0_3568res_2ms_DDS10_TIA0.png

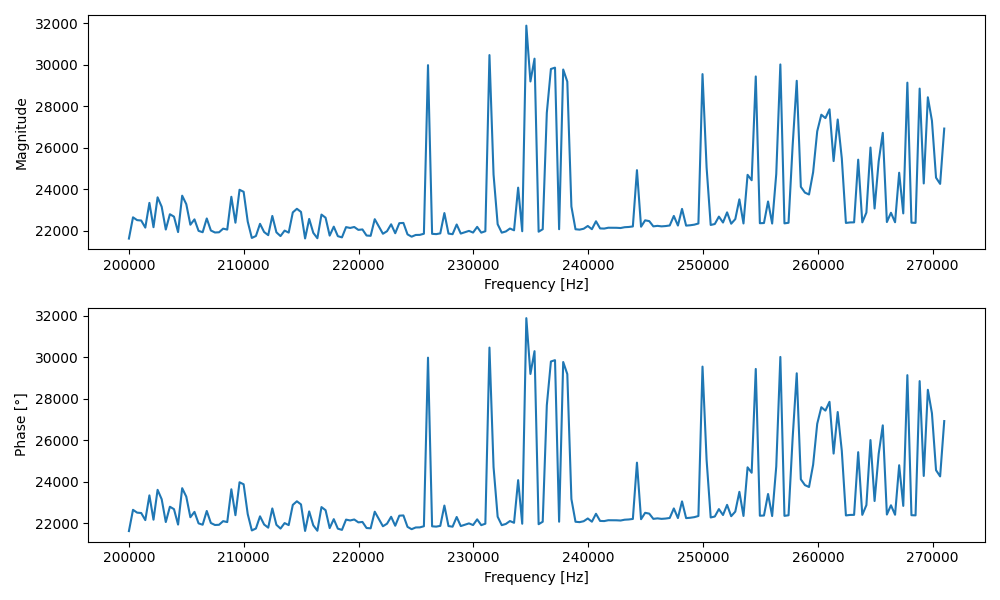
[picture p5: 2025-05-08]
measurements/TIA test/sweep_200.0_271.0_3568res_2ms_DDS10_TIA6.png

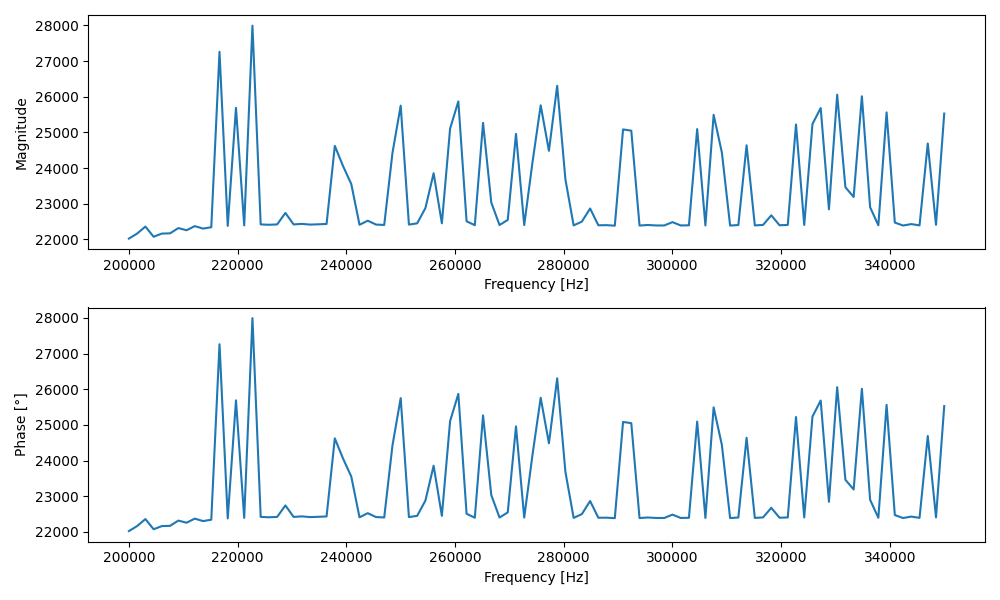
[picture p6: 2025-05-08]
measurements/TIA test/sweep_200.0_350.0_15152res_2ms_DDS10_TIA3.png

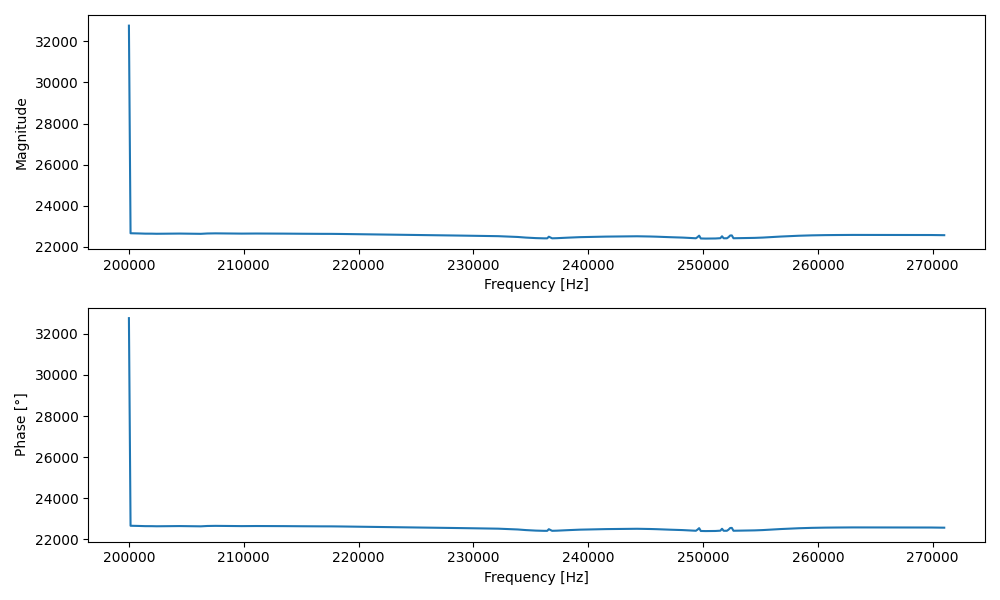
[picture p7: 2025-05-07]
measurements/dwell test/sweep_200.0_271.0_1423res_10ms_DDS255_TIA0.png

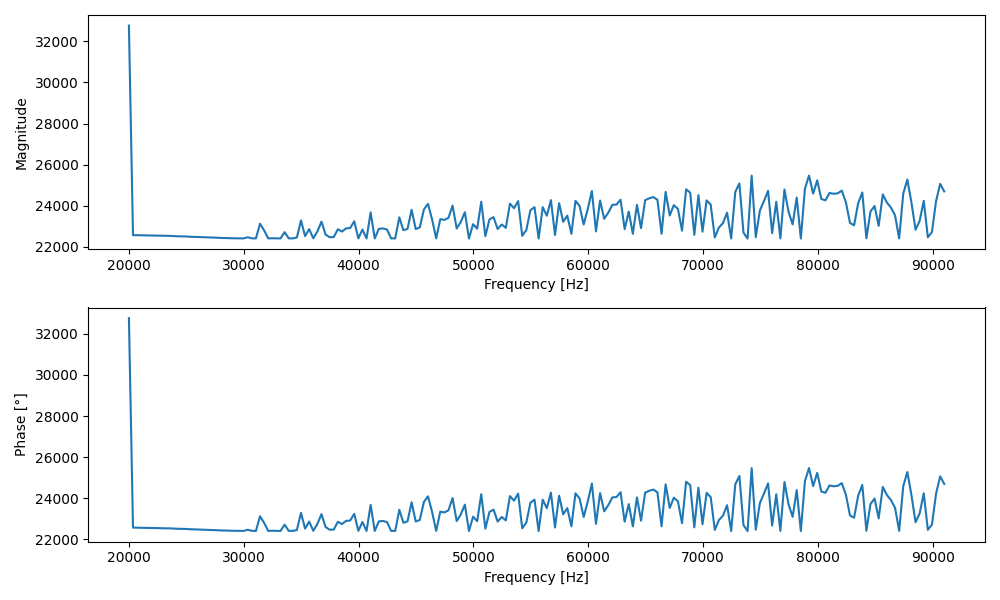
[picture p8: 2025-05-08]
measurements/TIA test/sweep_20.0_91.0_3568res_2ms_DDS10_TIA1.png

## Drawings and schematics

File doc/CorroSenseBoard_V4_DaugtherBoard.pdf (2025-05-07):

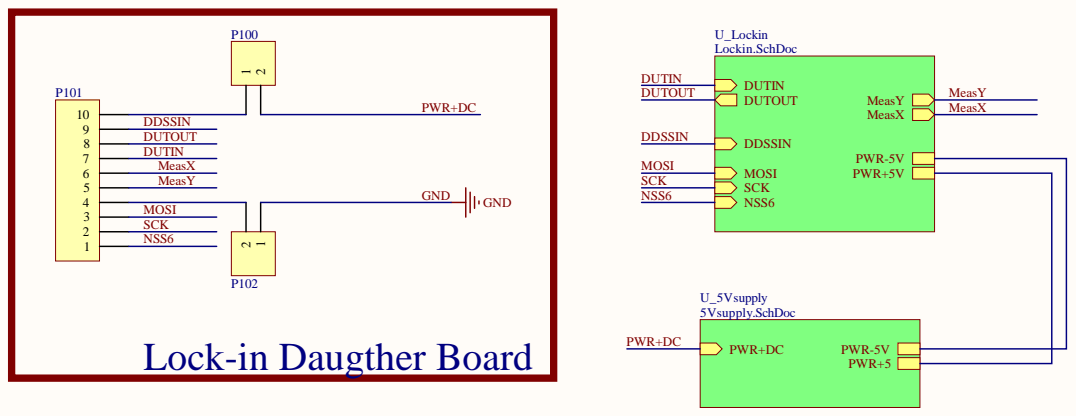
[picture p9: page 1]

Lock-in Daugther Board 12

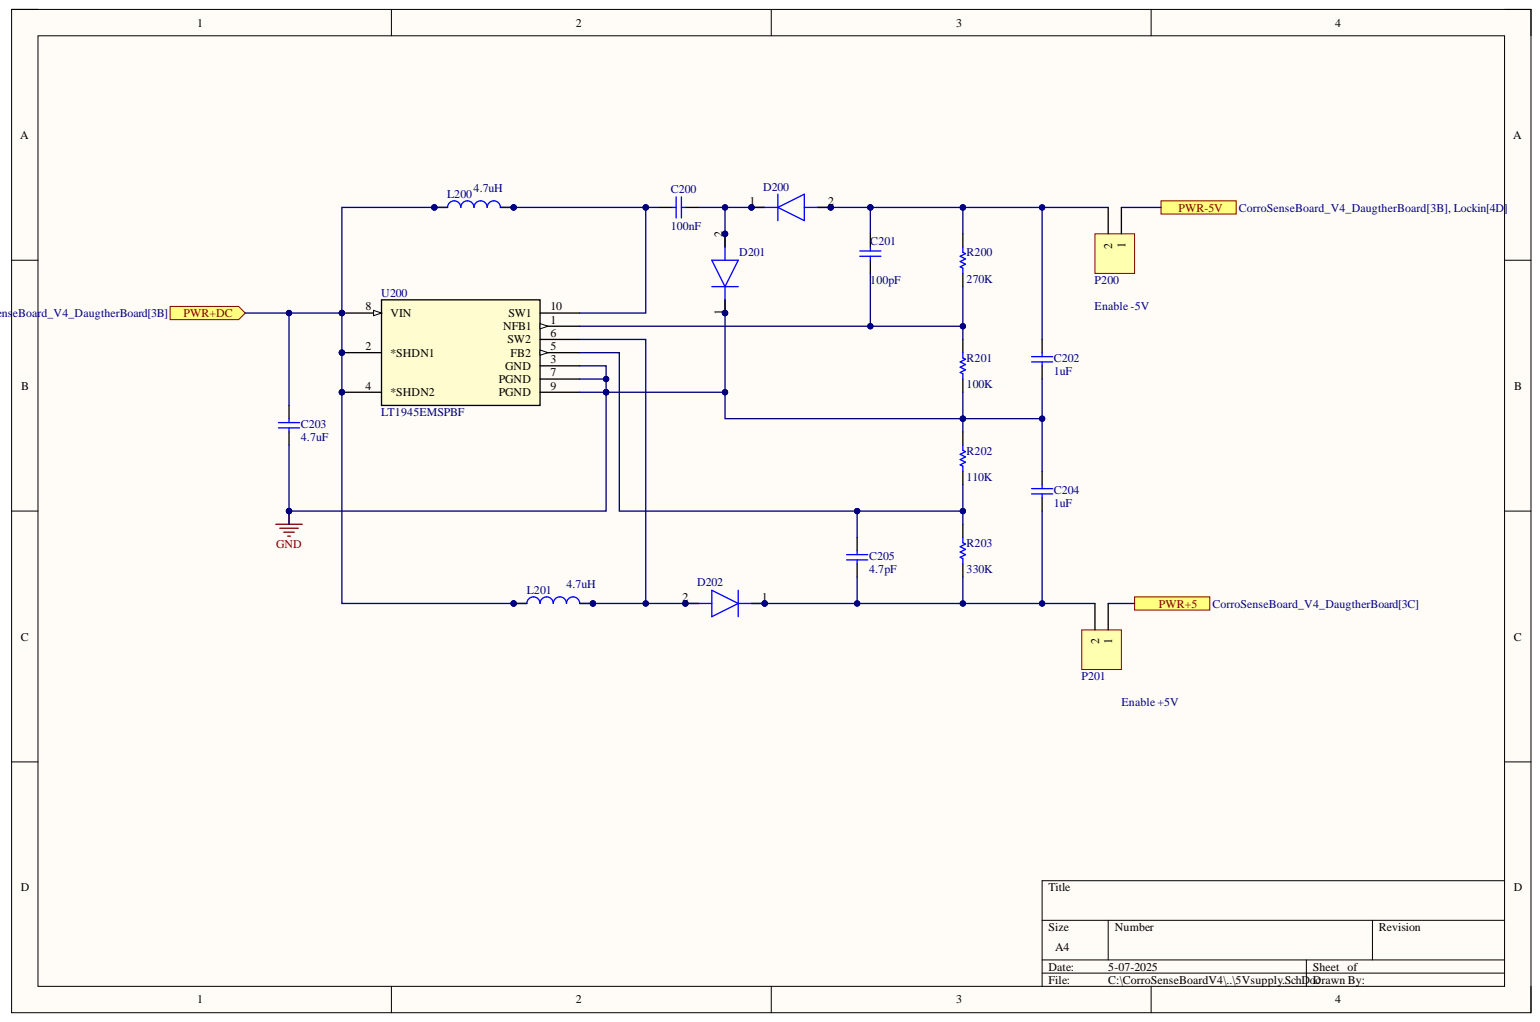
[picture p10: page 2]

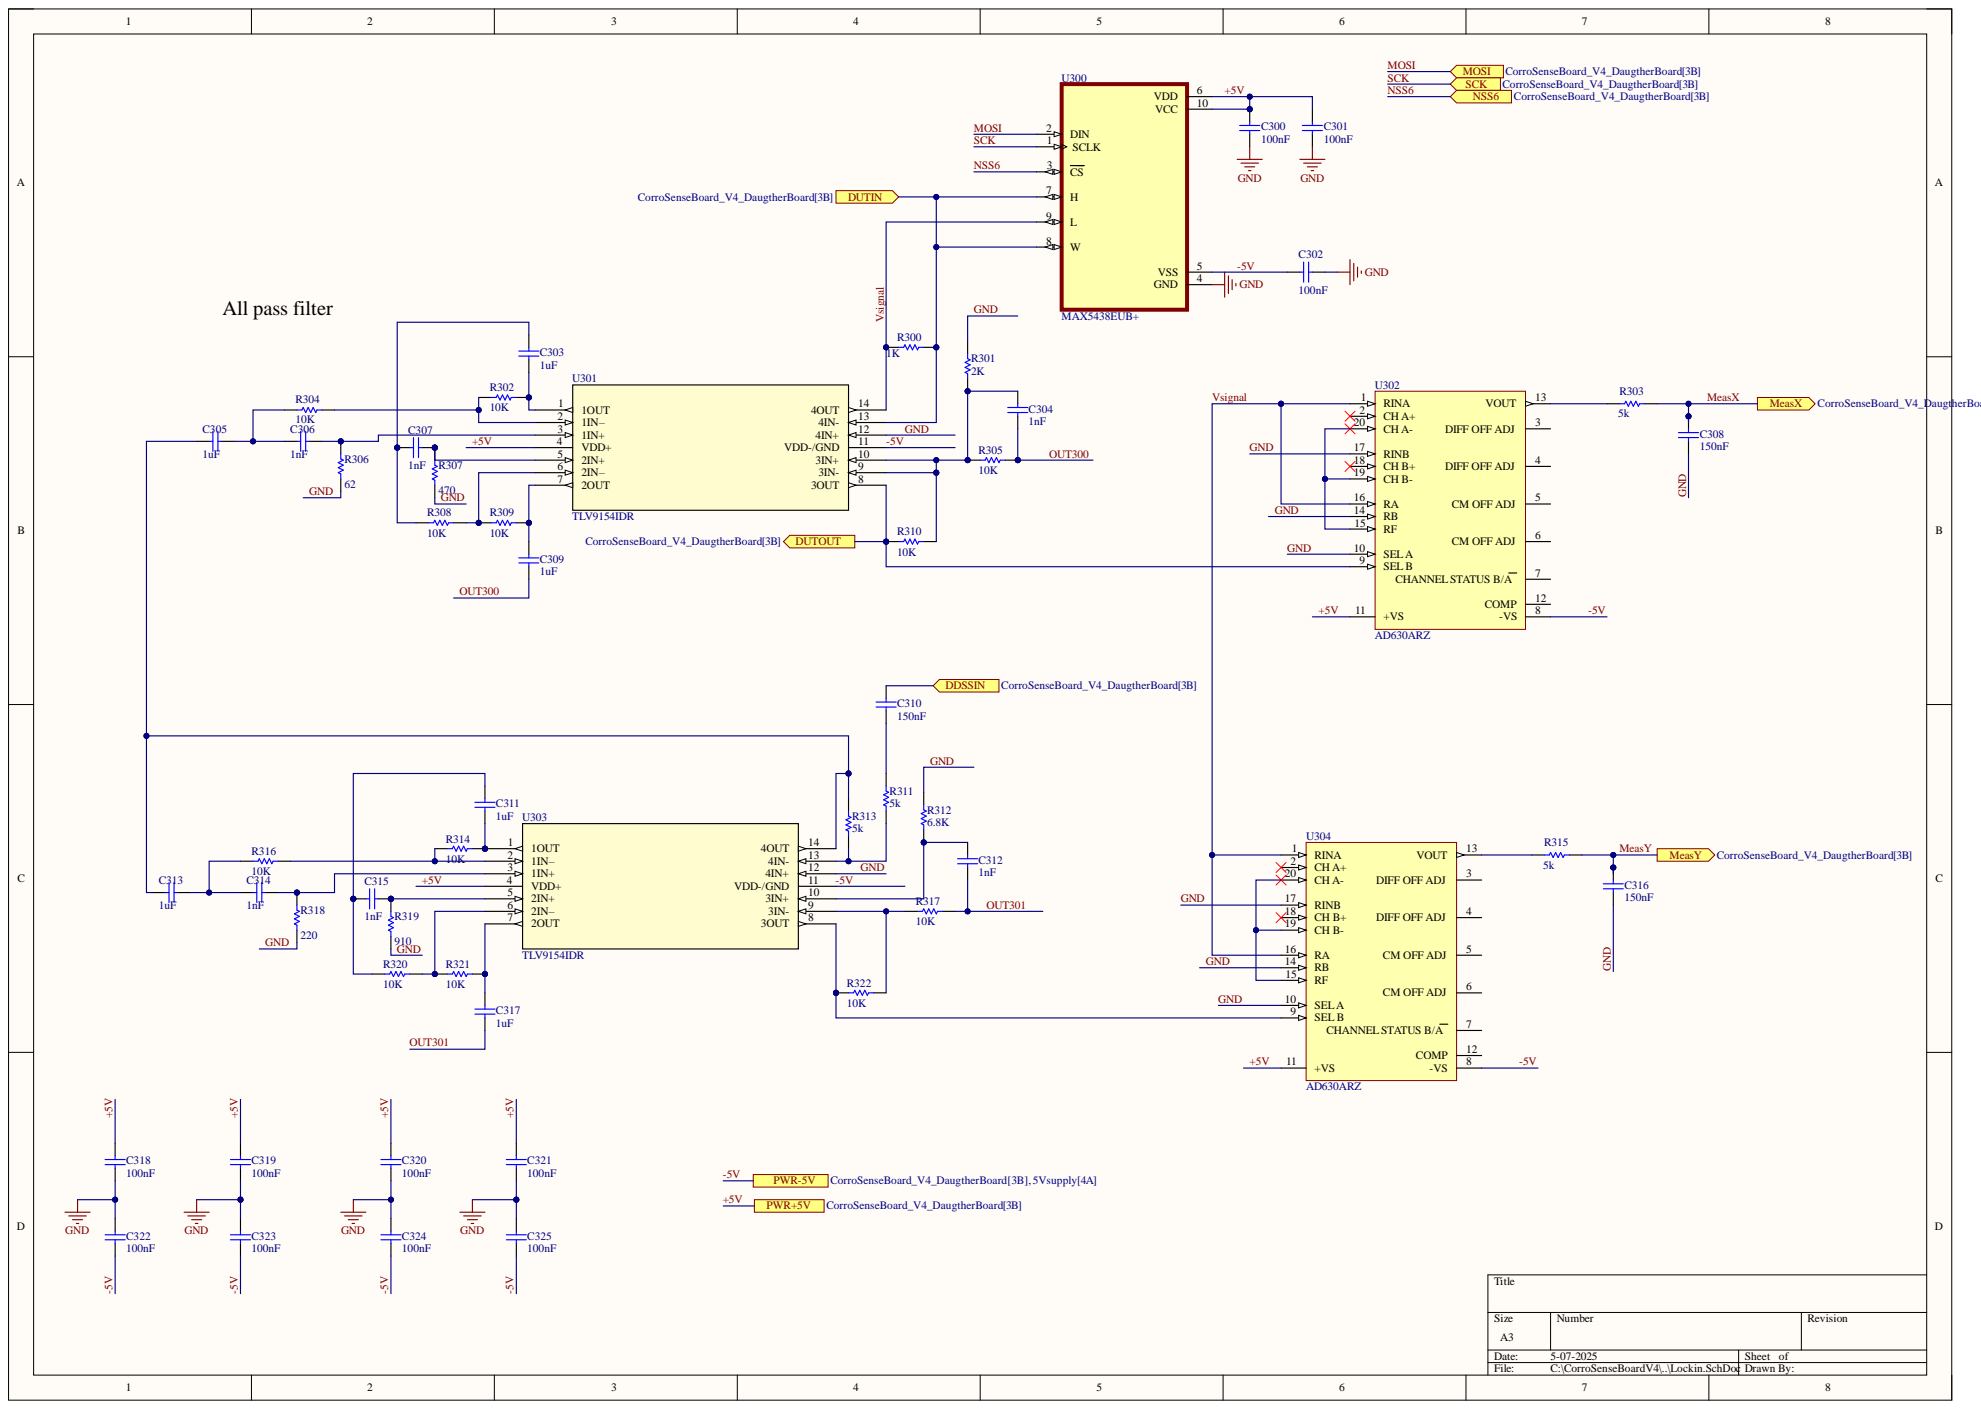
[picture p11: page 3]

GND

RA 16
RB 14 RF 15

2IN+ 5
2IN– 6

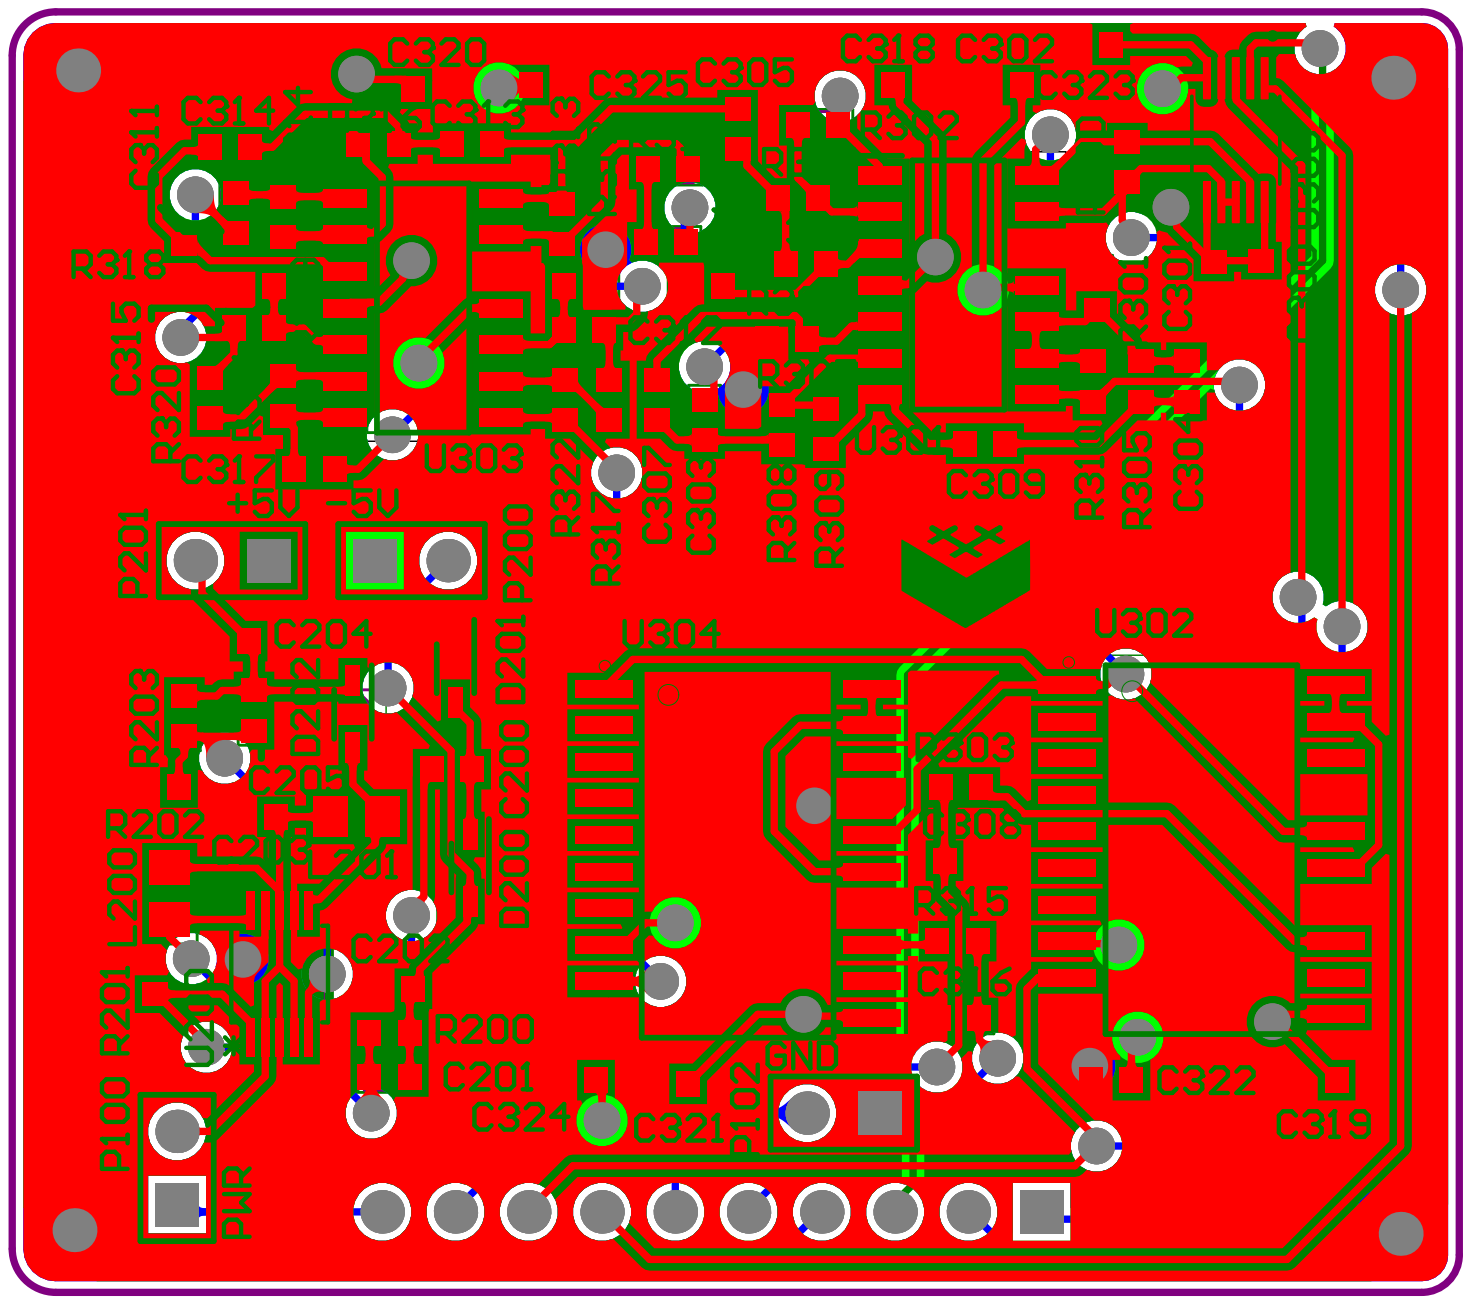
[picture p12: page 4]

Comment | Description | Designator | Footprint | LibRef | Quantity
100nF | CAPCER25VX7R0603 | C200, C300, C301, C302, C318, C319, C320, C321, C322, C323, C324, C325 | 1608[0603] | Cap | 12
100pF | CAPCER25VX7R0603 | C201 | 1608[0603] | Cap | 1
1uF | CAPCER25VX7R0603 | C202, C204, C303, C305, C309, C311, C313, C317 | 1608[0603] | Cap | 8
4.7uF | CAPCER25VX7R0603 | C203 | 1608[0603] | Cap | 1
4.7pF | CAPCER25VX7R0603 | C205 | 1608[0603] | Cap | 1
1nF | CAPCER25VX7R0603 | C304, C306, C307, C312, C314, C315 | 1608[0603] | Cap | 6
150nF | CAPCER25VX7R0603 | C308, C310, C316 | 1608[0603] | Cap | 3
ZHCS400TA | Diode | D200, D201, D202 | SOD2513X120N | ZHCS400TA | 3
LQM18PN4R7MFRL | FIXEDIND4.7UH 620MA550MOHMSM | L200, L201 | 6-0805_N | Inductor | 2
Header, 2-Pin | Header, 2-Pin | P100, P102, P200, P201 | HDR1X2 | Header 2 | 4
Header, 10-Pin | Header, 10-Pin | P101 | HDR1X10 | Header 10 | 1
270K | RESSMD2%1.5W 0603 | R200 | 1608[0603] | Res1 | 1
100K | RESSMD2%1.5W 0603 | R201 | 1608[0603] | Res1 | 1
110K | RESSMD2%1.5W 0603 | R202 | 1608[0603] | Res1 | 1
330K | RESSMD2%1.5W 0603 | R203 | 1608[0603] | Res1 | 1
1K | RESSMD2%1.5W 0603 | R300 | 1608[0603] | Res1 | 1
2K | RESSMD2%1.5W 0603 | R301 | 1608[0603] | Res1 | 1
10K | RESSMD2%1.5W 0603 | R302, R304, R305, R308, R309, R310, R314, R316, R317, R320, R321, R322 | 1608[0603] | Res1 | 12
5k | RESSMD2%1.5W 0603 | R303, R311, R313, R315 | 1608[0603] | Res1 | 4
62 | RESSMD2%1.5W 0603 | R306 | 1608[0603] | Res1 | 1
470 | RESSMD2%1.5W 0603 | R307 | 1608[0603] | Res1 | 1
6.8K | RESSMD2%1.5W 0603 | R312 | 1608[0603] | Res1 | 1
220 | RESSMD2%1.5W 0603 | R318 | 1608[0603] | Res1 | 1
910 | RESSMD2%1.5W 0603 | R319 | 1608[0603] | Res1 | 1
LT1945EMSPBF | No Description Available | U200 | MSOP-10_MS_LIT | LT1945EMSPBF | 1
MAX5438EUB+ | | U300 | SOP50P490X110-10N | MAX5438EUB+ | 1
TLV9154IDR | No Description Available | U301, U303 | SOIC127P600X175-14N | TLV2444CD | 2
AD630ARZ | Consumer Circuit, PDSO20 | U302, U304 | SOIC127P1032X265-20N | ADI-AD630-RW-20 | 2

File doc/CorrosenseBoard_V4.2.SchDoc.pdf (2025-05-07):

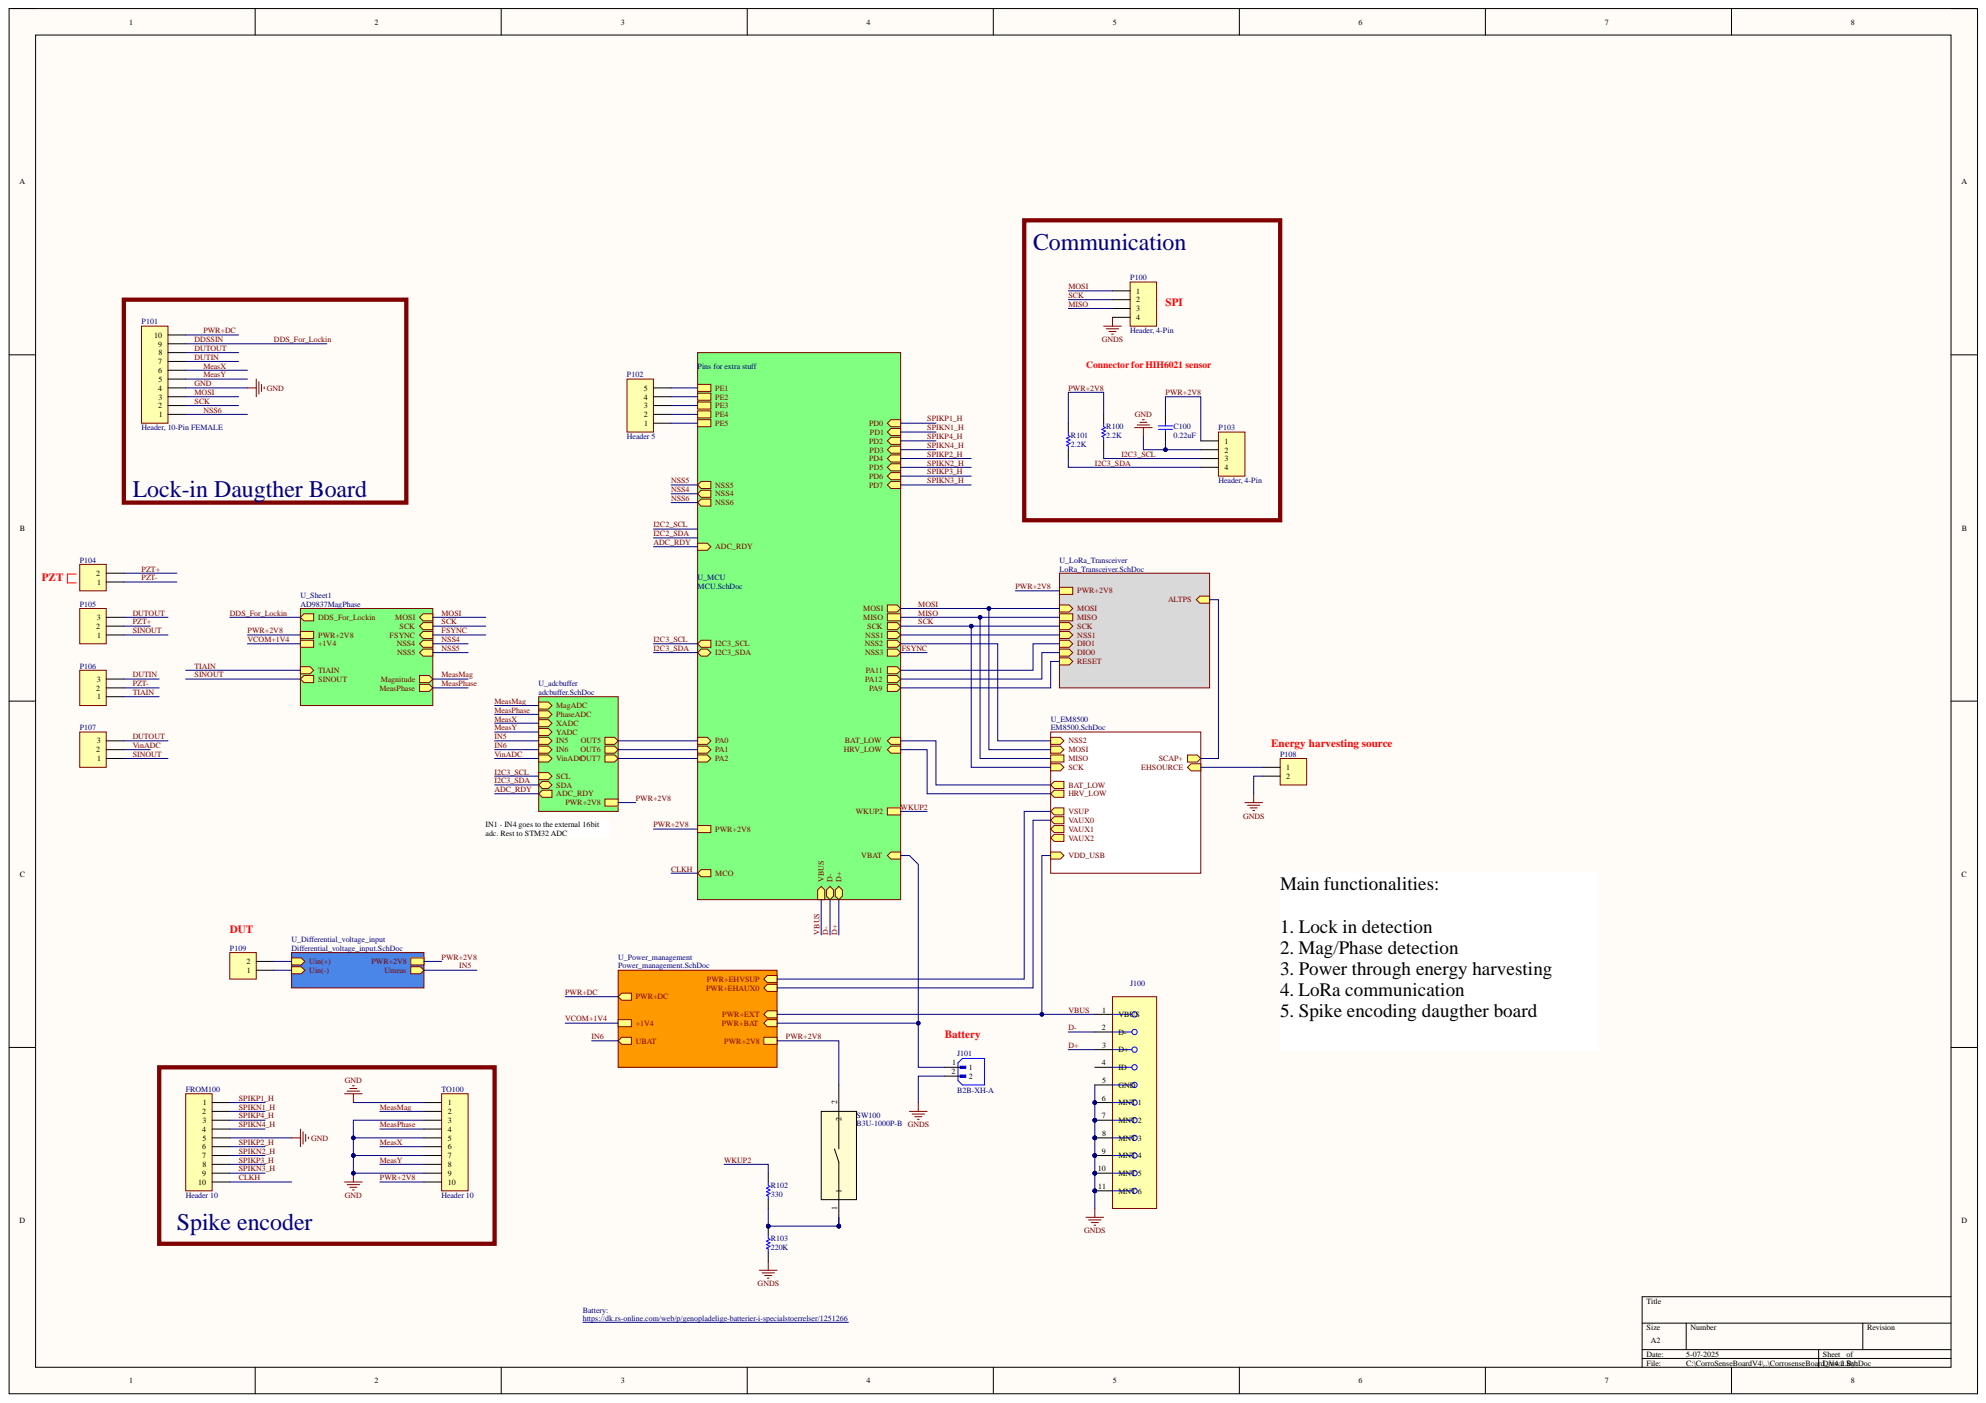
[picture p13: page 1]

Pins for extra stuff

IN1 - IN4 goes to the external 16bit
adc. Rest to STM32 ADC

1. Lock in detection
2. Mag/Phase detection
3. Power through energy harvesting
4. LoRa communication
5. Spike encoding daugther board

Battery:
https://dk.rs-online.com/web/p/genopladelige-batterier-i-specialstoerrelser/1251266

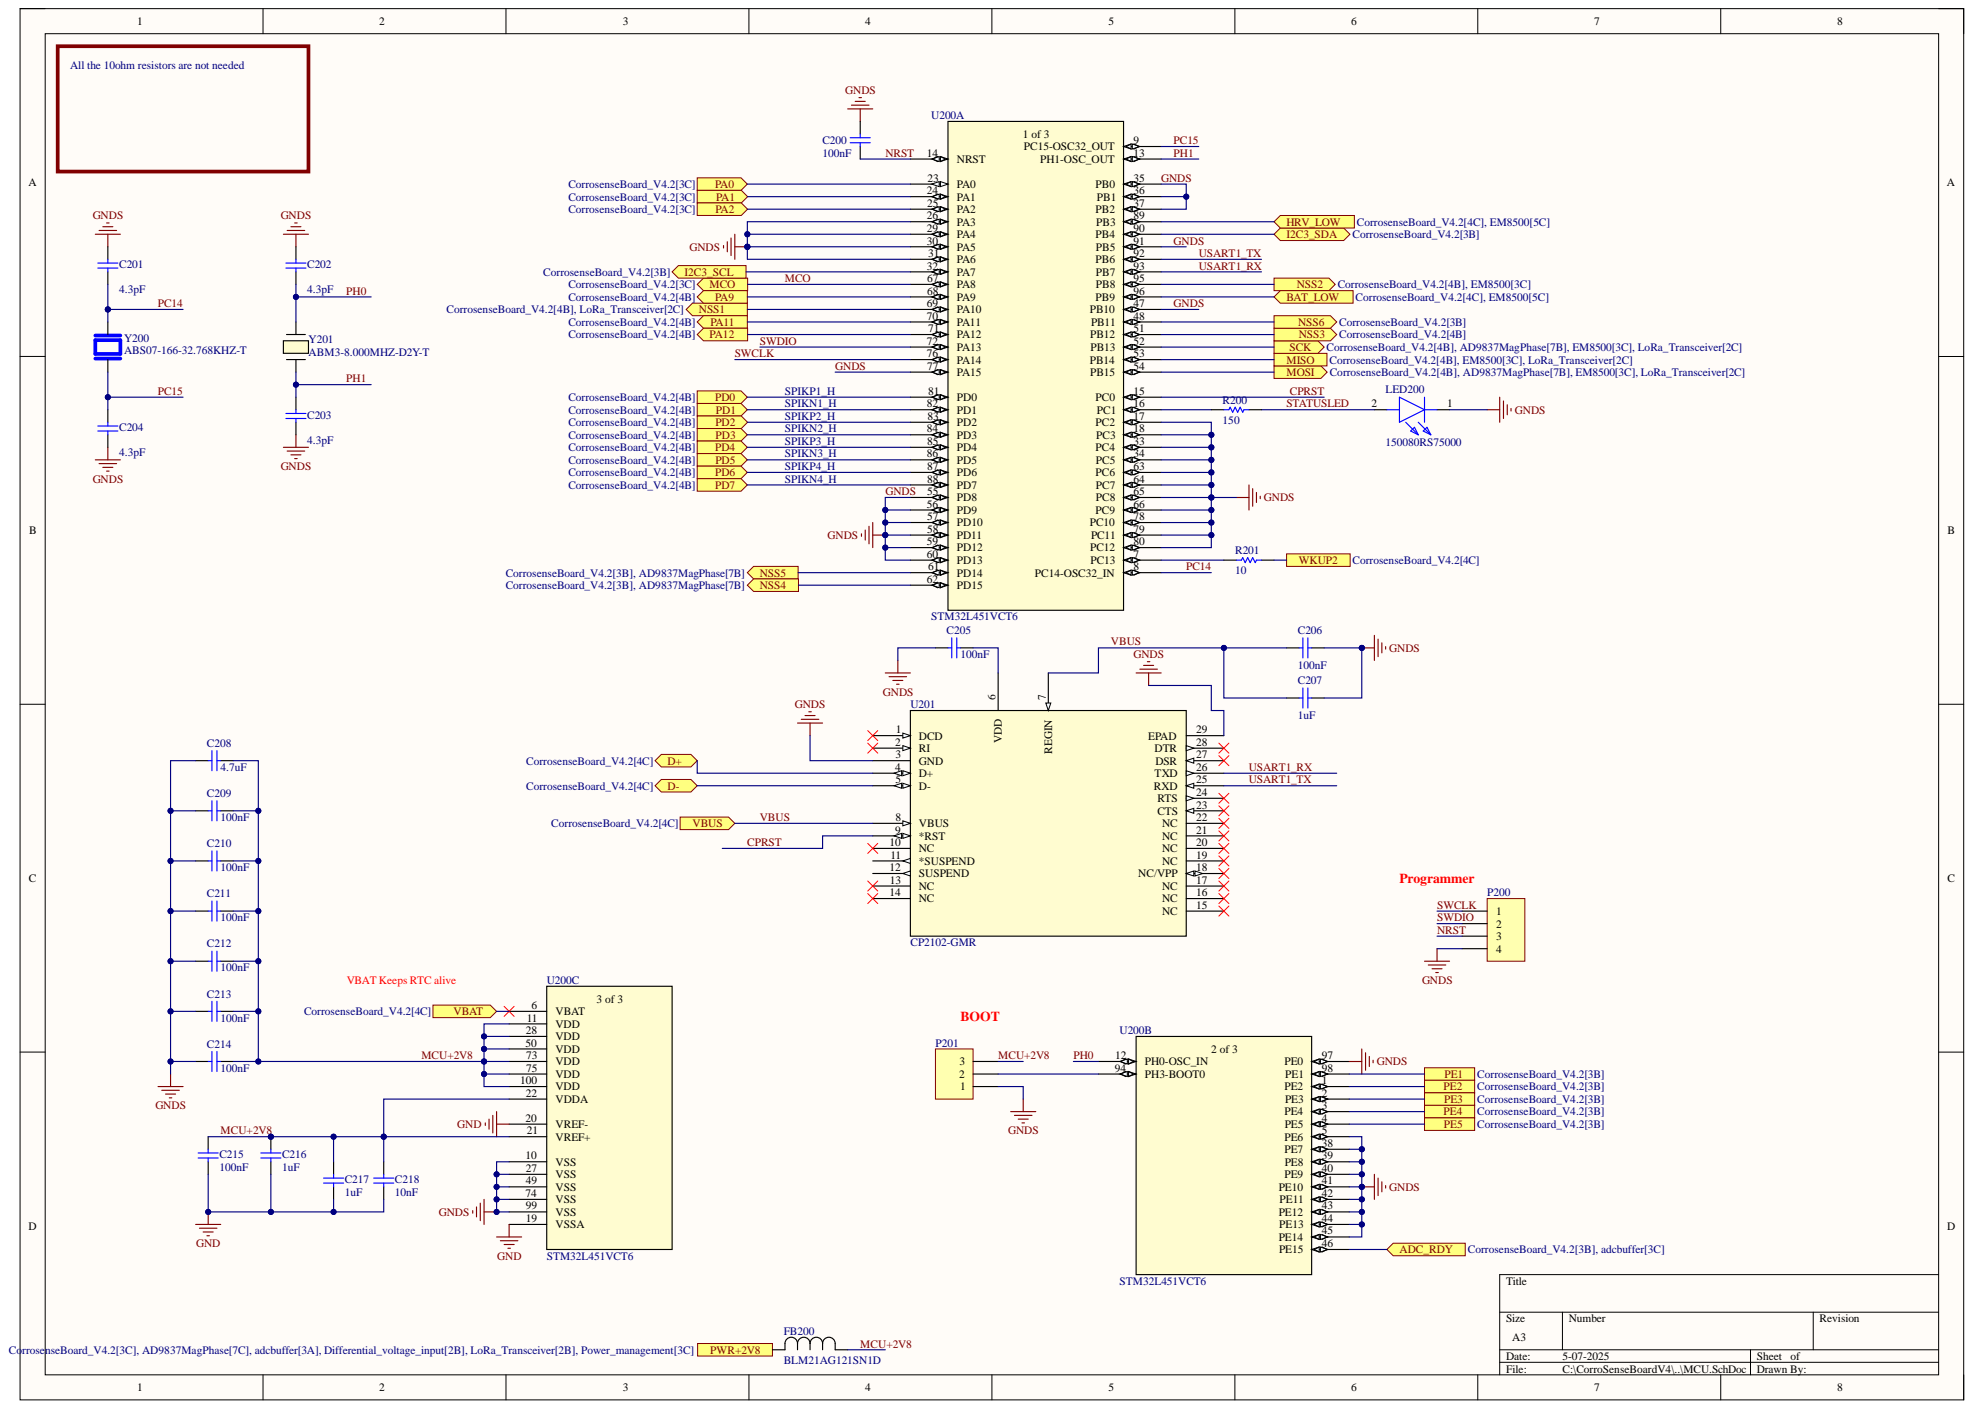
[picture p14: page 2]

All the 10ohm resistors are not needed

VBAT Keeps RTC alive

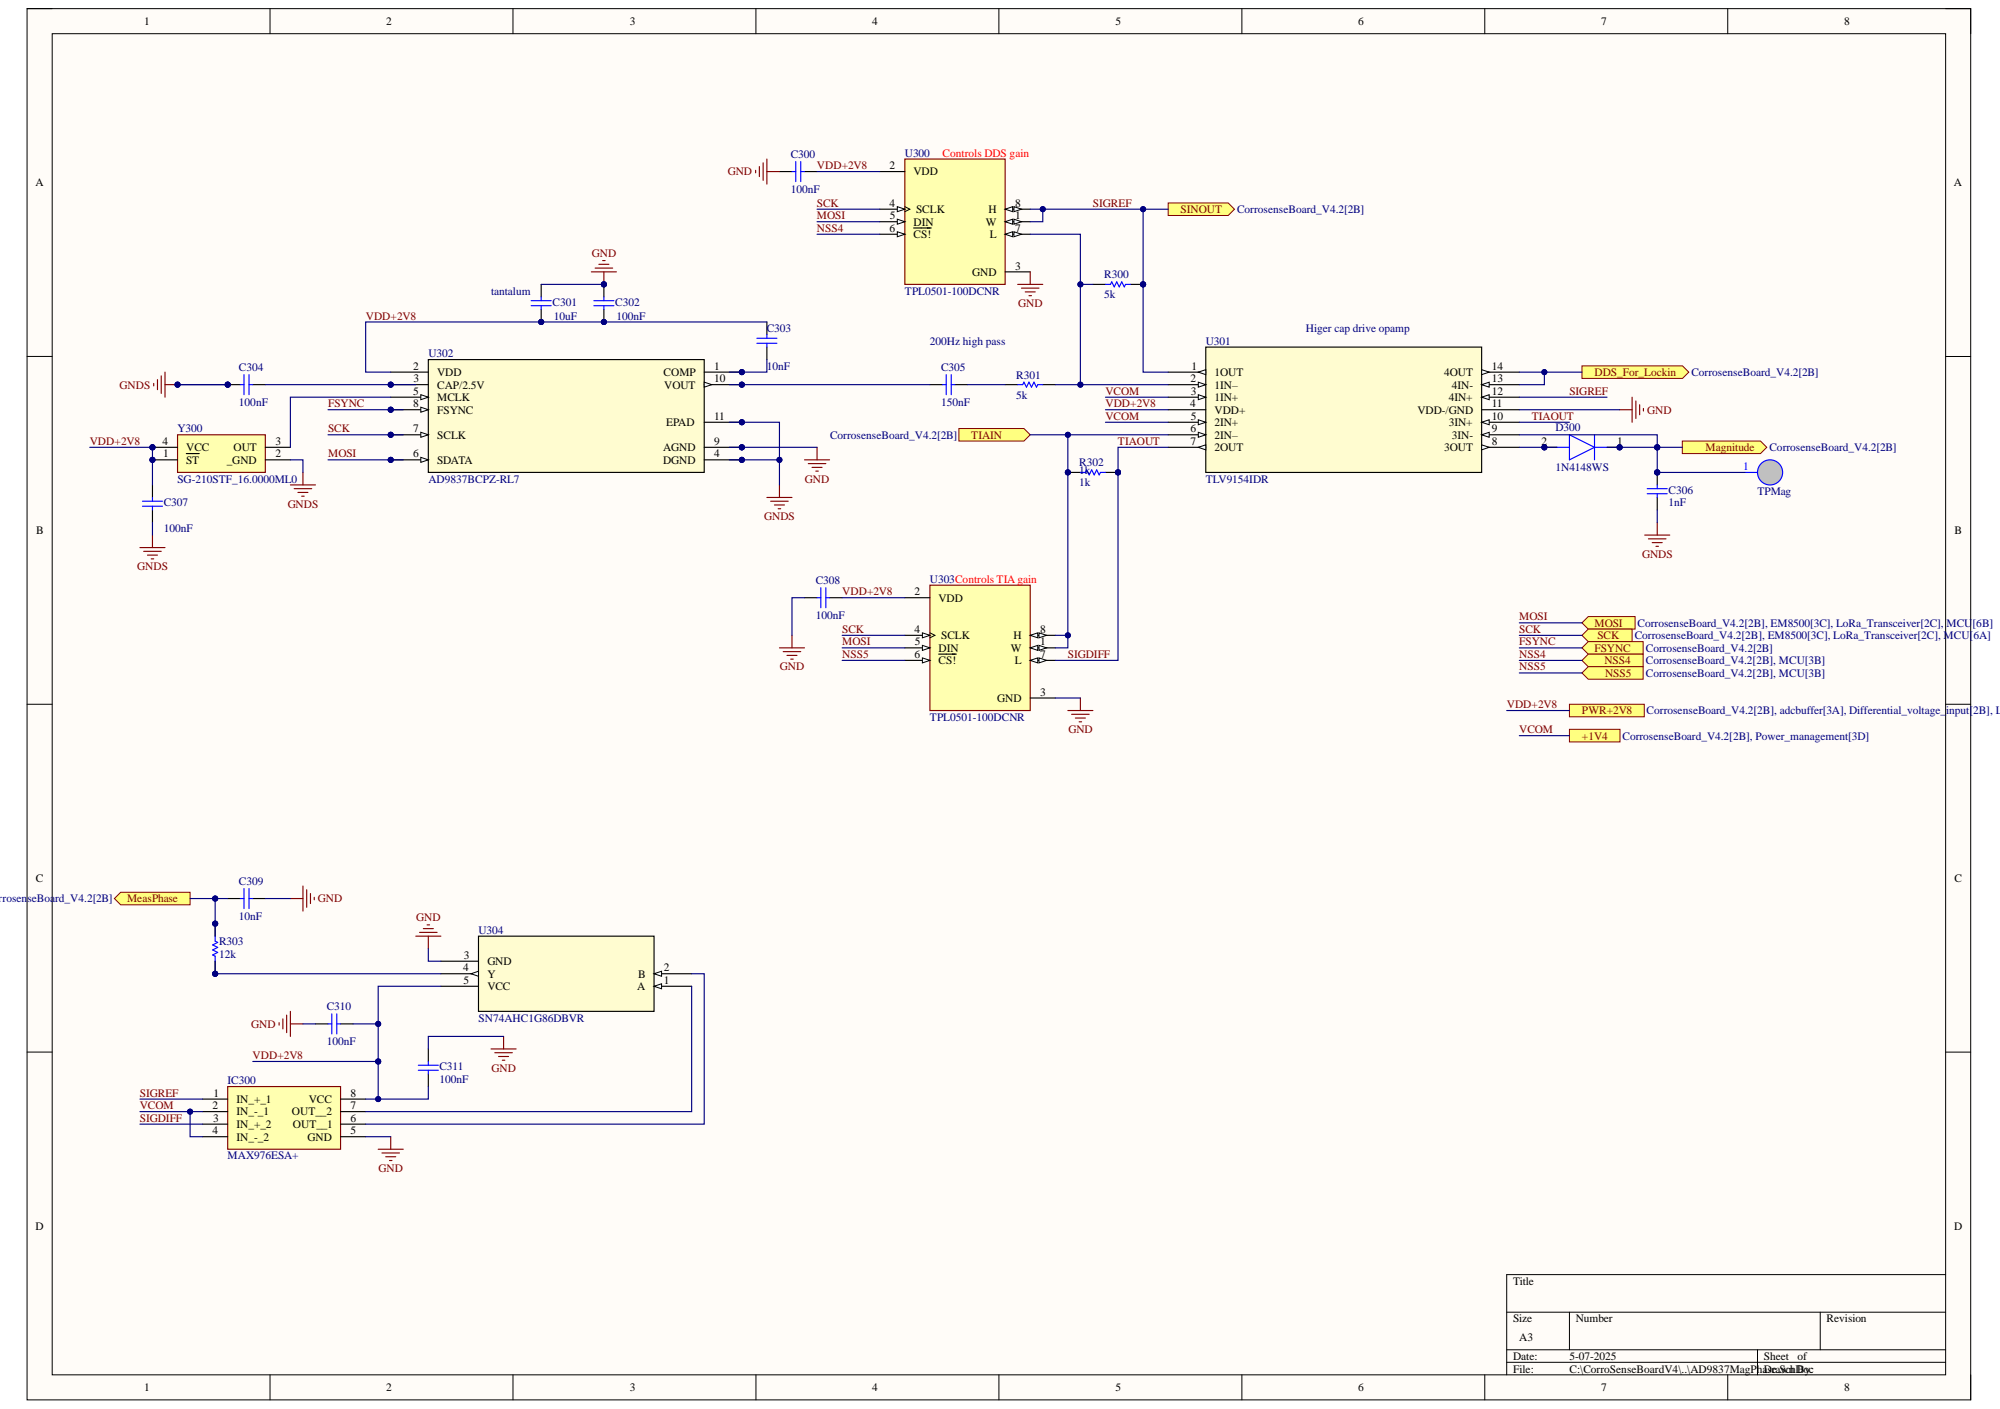
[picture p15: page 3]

Higer cap drive opamp

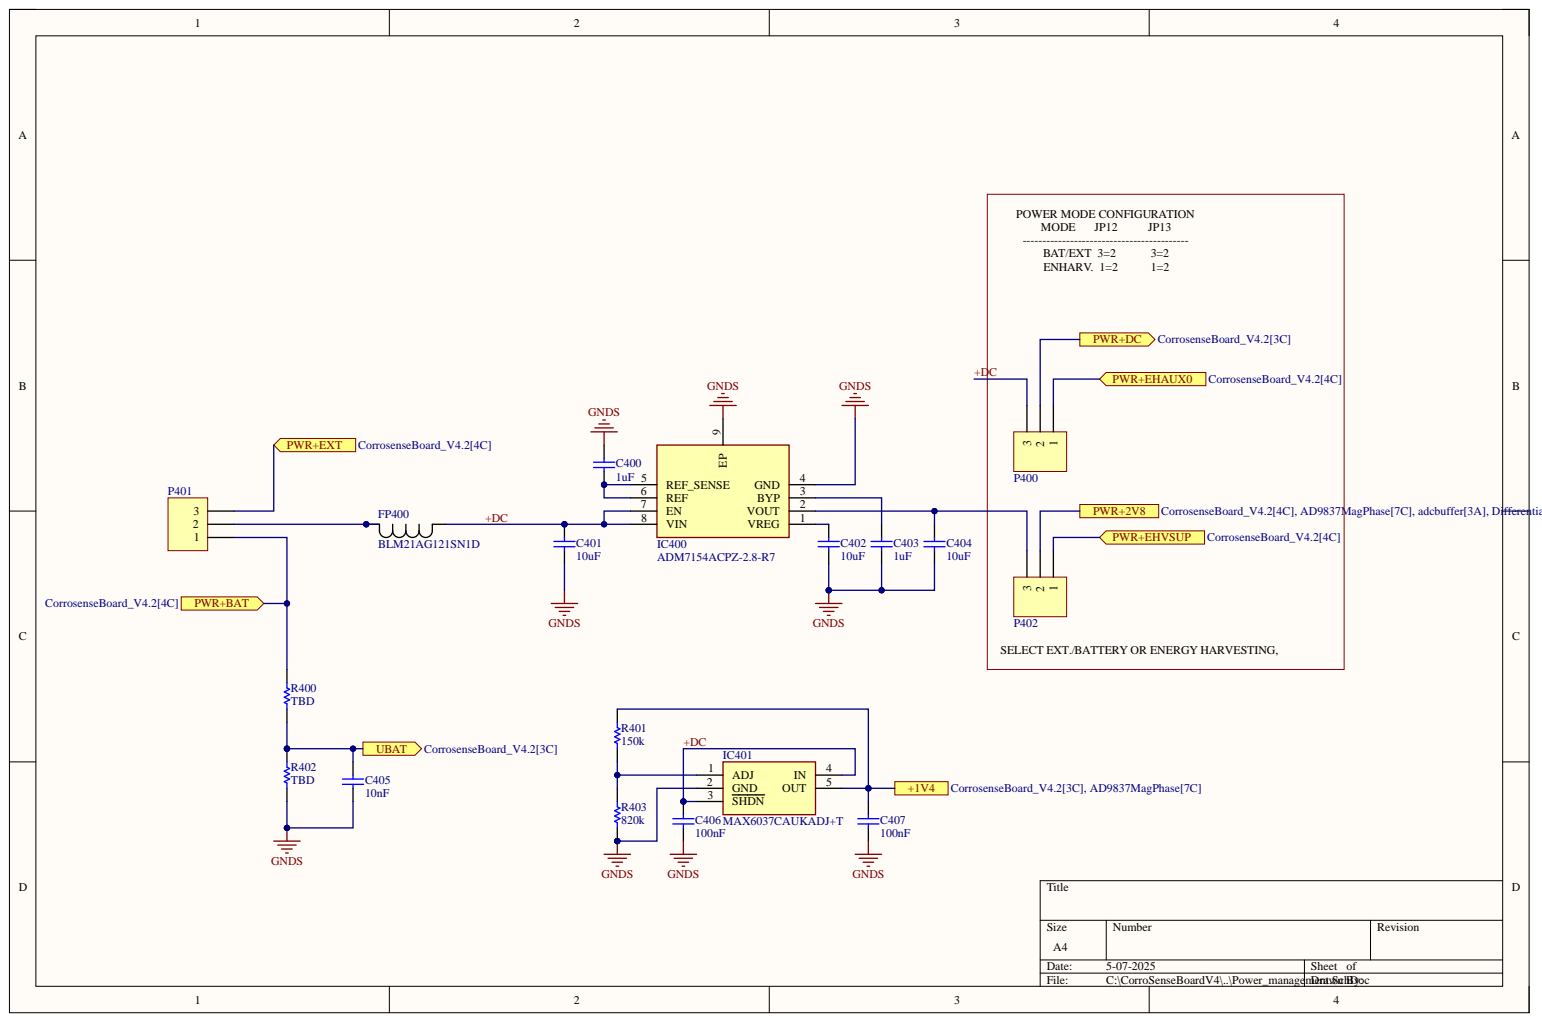
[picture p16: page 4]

C402
10uF | 1uF

SELECT EXT./BATTERY OR ENERGY HARVESTING,

GND 2
SHDN 3

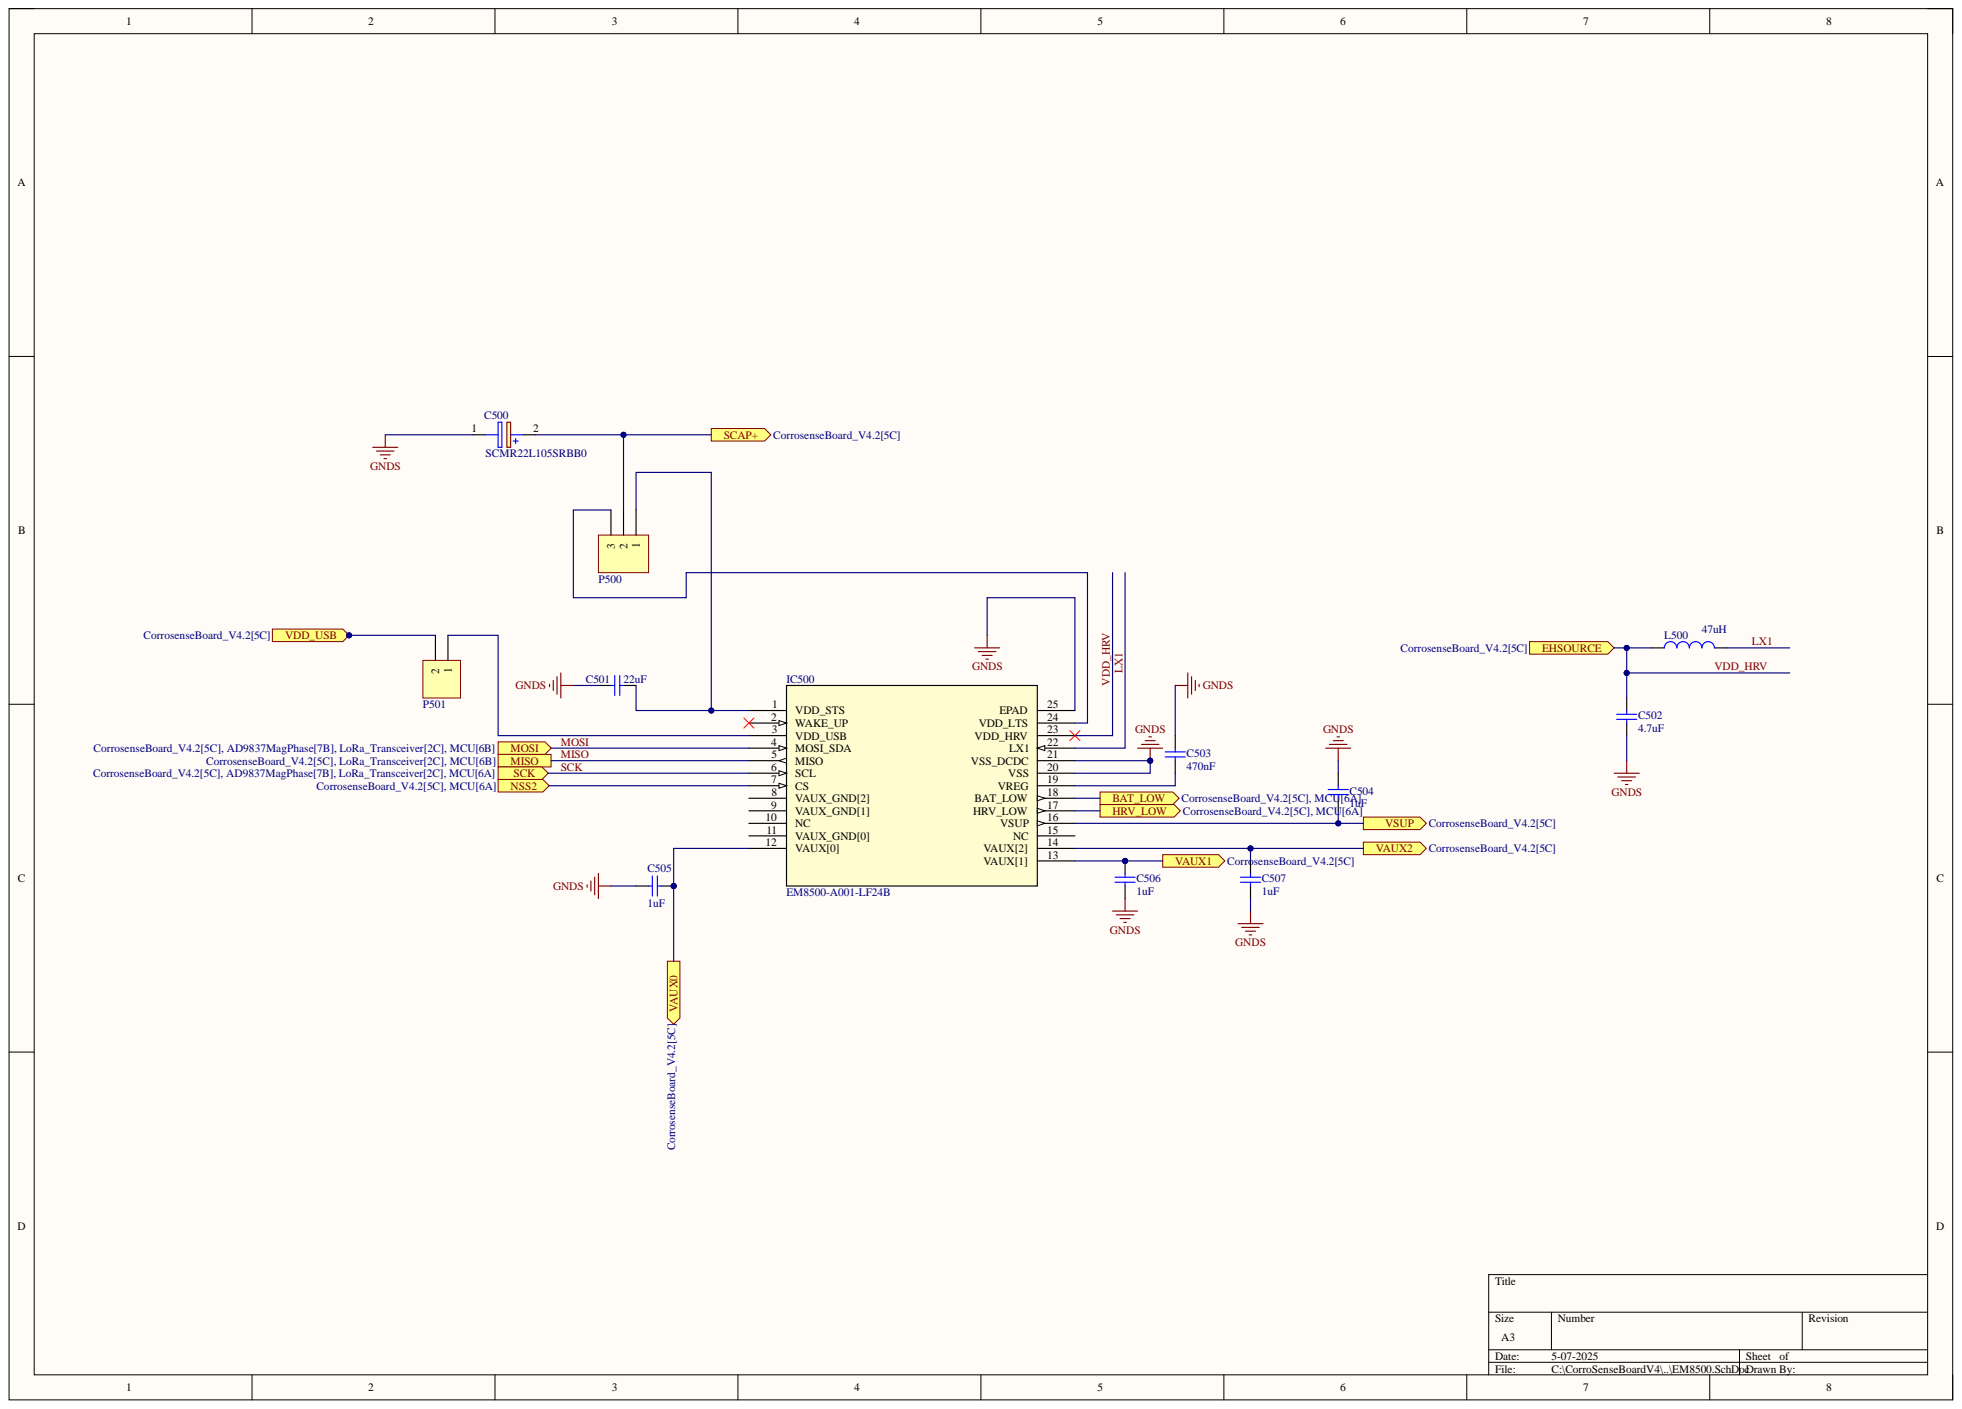
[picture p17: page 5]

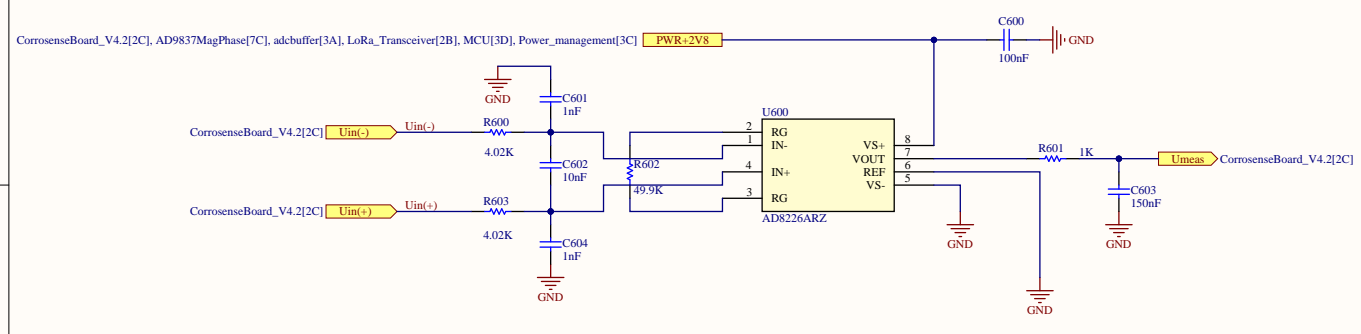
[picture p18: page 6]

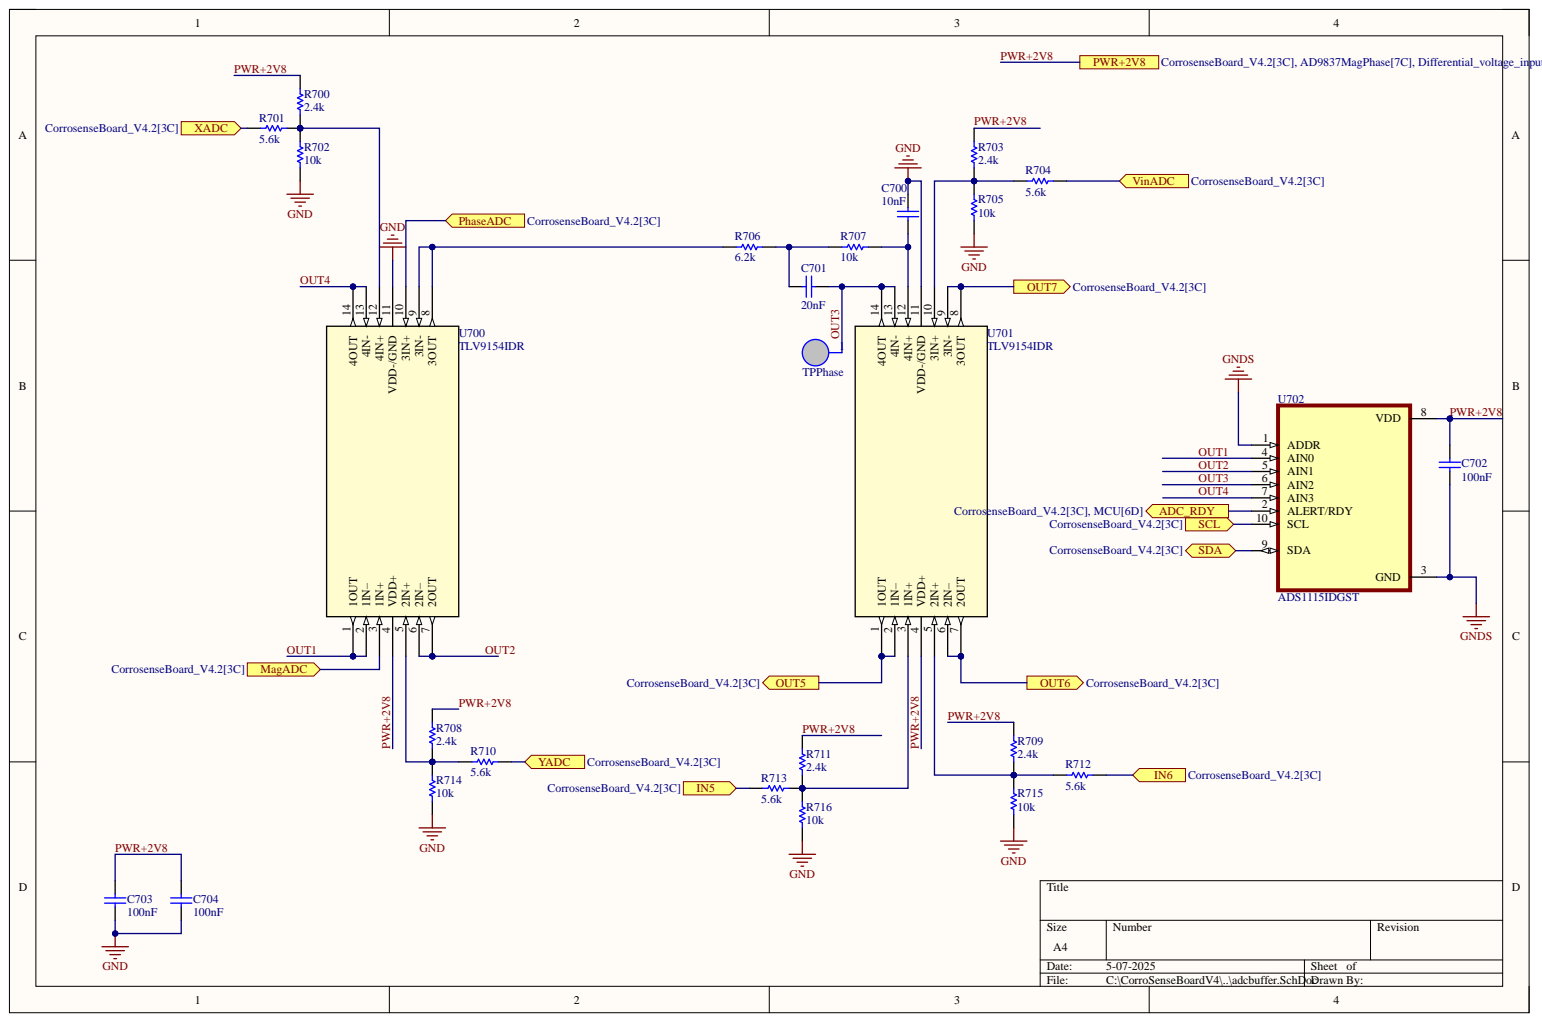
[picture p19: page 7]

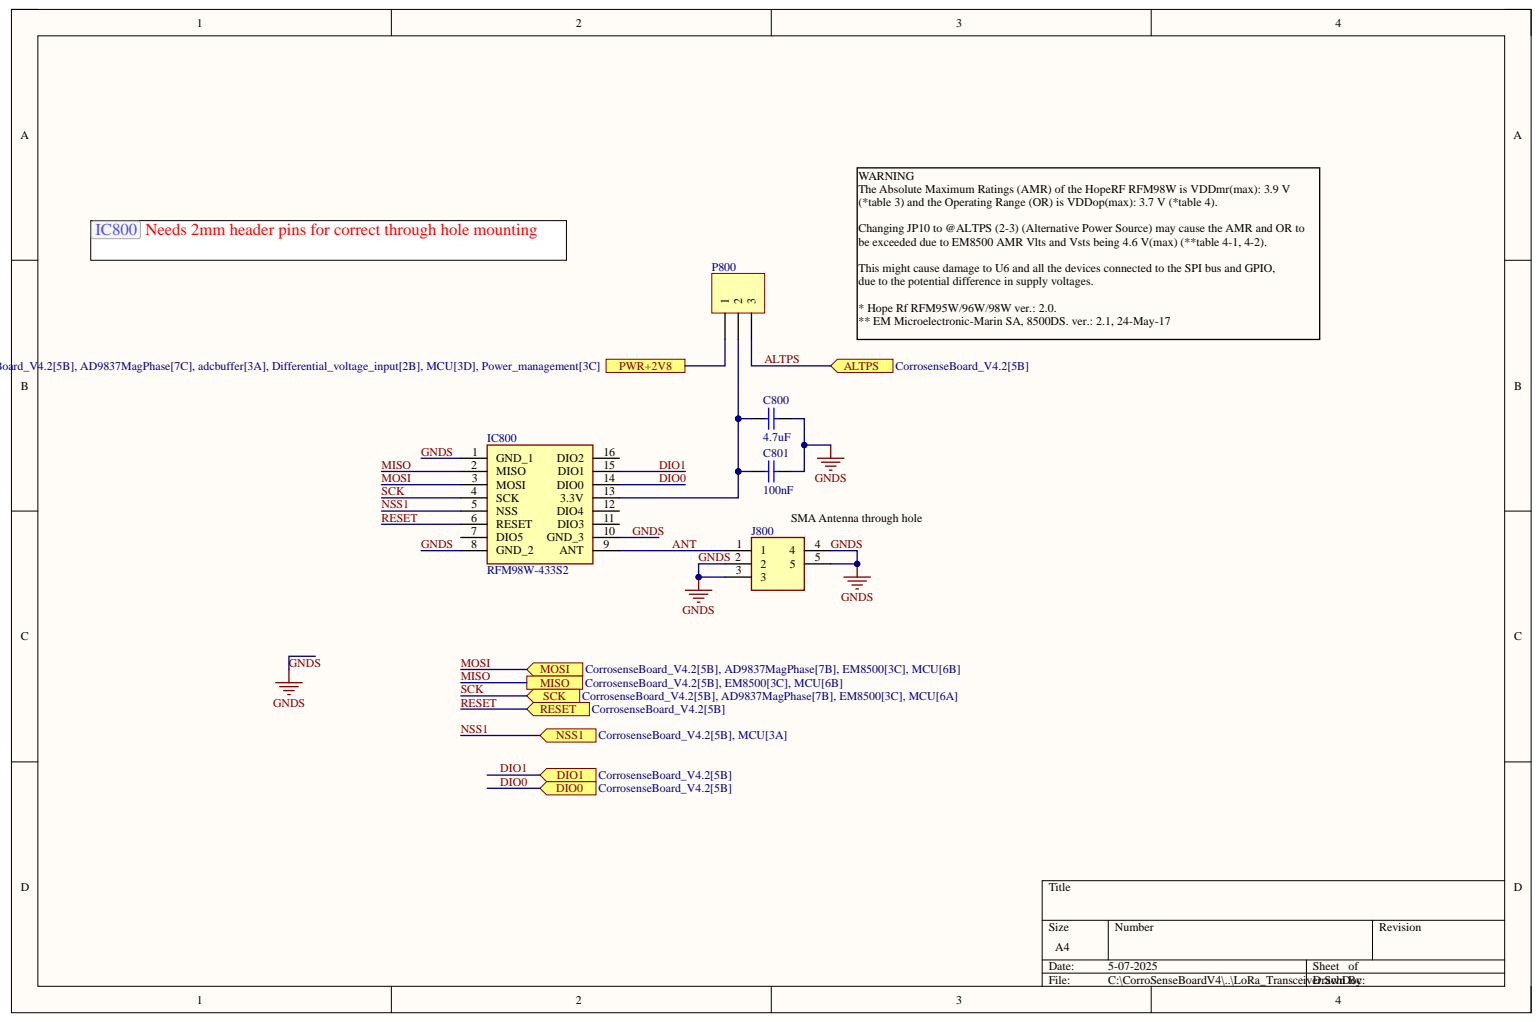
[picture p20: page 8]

WARNING
The Absolute Maximum Ratings (AMR) of the HopeRF RFM98W is VDDmr(max): 3.9 V
(*table 3) and the Operating Range (OR) is VDDop(max): 3.7 V (*table 4).

IC800 Needs 2mm header pins for correct through hole mounting

Changing JP10 to @ALTPS (2-3) (Alternative Power Source) may cause the AMR and OR to
be exceeded due to EM8500 AMR Vlts and Vsts being 4.6 V(max) (**table 4-1, 4-2).

This might cause damage to U6 and all the devices connected to the SPI bus and GPIO,
due to the potential difference in supply voltages.

* Hope Rf RFM95W/96W/98W ver.: 2.0.
** EM Microelectronic-Marin SA, 8500DS. ver.: 2.1, 24-May-17

SMA Antenna through hole


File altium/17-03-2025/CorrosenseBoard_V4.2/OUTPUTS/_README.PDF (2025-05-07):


Symbol | Count | Hole Size | Plated | Hole Tolerance

165 | 0.71mm | Plated
1 | 0.75mm | Non-Plated
16 | 0.80mm | Plated
2 | 0.85mm | Plated
82 | 0.90mm | Plated
2 | 1.05mm | Plated
5 | 1.60mm | Plated
4 | 3.10mm | Plated
277 Total

Drill Drawing View (Scale 3:2)

Notes:
1. Board type : Single
2. Material: FR4
3. LAYERS - 6
4. Thickness: 2.0 mm
5. Min Track/Spacing: 5/5 mil
6. Min Hole Size: 0.71 mm
7. Solder Mask: GREEN
8. Silkscreen: White
9. Surface Finish: Immersion gold (ENIG). Thickness: 1U"
10. Via Process : Tenting vias
11. Finished Copper: 1 oz Cu
12. Inner Copper: 1 oz Cu

UNLESS OTHERWISE SPECIFIED: | | NAME | DATE
DIMENSIONS ARE IN Millimeters TOLERANCES: FRACTIONAL± ANGULAR: MACH± BEND ± TWO PLACE DECIMAL ± THREE PLACE DECIMAL ± | DRAWN | | 17/03/2025

CHECKED | | | TITLE =DT_SCH_Title
ENG APPR.

THE INFORMATION CONTAINED IN THIS DRAWING IS THE SOLE PROPERTY OF . ANY REPRODUCTION IN PART OR AS A WHOLE PROPRIETARY AND CONFIDENTIAL | | | MFG APPR.

INTERPRET GEOMETRIC TOLERANCING PER: | Q.A.

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

CHECKED | | | TITLE =DT_SCH_Title
ENG APPR.

THE INFORMATION CONTAINED IN THIS DRAWING IS THE SOLE PROPERTY OF | | | MFG APPR.

INTERPRET GEOMETRIC TOLERANCING PER: | Q.A.

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

CHECKED | | | TITLE =DT_SCH_Title
ENG APPR.

THE INFORMATION CONTAINED IN THIS DRAWING IS THE SOLE PROPERTY OF | | | MFG APPR.

INTERPRET GEOMETRIC TOLERANCING PER: | Q.A.

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

CHECKED | | | TITLE =DT_SCH_Title
ENG APPR.

THE INFORMATION CONTAINED IN THIS DRAWING IS THE SOLE PROPERTY OF | | | MFG APPR.

INTERPRET GEOMETRIC TOLERANCING PER: | Q.A.

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

CHECKED | | | TITLE =DT_SCH_Title
ENG APPR.

THE INFORMATION CONTAINED IN THIS DRAWING IS THE SOLE PROPERTY OF | | | MFG APPR.

INTERPRET GEOMETRIC TOLERANCING PER: | Q.A.

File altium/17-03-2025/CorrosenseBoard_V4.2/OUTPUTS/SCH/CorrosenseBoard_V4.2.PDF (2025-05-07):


Pins for extra stuff

IN1 - IN4 goes to the external 16bit
adc. Rest to STM32 ADC

1. Lock in detection
2. Mag/Phase detection
3. Power through energy harvesting
4. LoRa communication
5. Spike encoding daugther board

Battery:
https://dk.rs-online.com/web/p/genopladelige-batterier-i-specialstoerrelser/1251266


All the 10ohm resistors are not needed

PA4 29
PA5 30

VBAT Keeps RTC alive


Higer cap drive opamp


C402
10uF | 1uF

SELECT EXT./BATTERY OR ENERGY HARVESTING,





WARNING
The Absolute Maximum Ratings (AMR) of the HopeRF RFM98W is VDDmr(max): 3.9 V
(*table 3) and the Operating Range (OR) is VDDop(max): 3.7 V (*table 4).

IC800 Needs 2mm header pins for correct through hole mounting

Changing JP10 to @ALTPS (2-3) (Alternative Power Source) may cause the AMR and OR to
be exceeded due to EM8500 AMR Vlts and Vsts being 4.6 V(max) (**table 4-1, 4-2).

This might cause damage to U6 and all the devices connected to the SPI bus and GPIO,
due to the potential difference in supply voltages.

* Hope Rf RFM95W/96W/98W ver.: 2.0.
** EM Microelectronic-Marin SA, 8500DS. ver.: 2.1, 24-May-17

SMA Antenna through hole

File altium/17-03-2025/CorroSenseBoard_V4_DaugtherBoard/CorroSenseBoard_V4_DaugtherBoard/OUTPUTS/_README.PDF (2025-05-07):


Drill Drawing View (Scale 3:1)

Symbol | Count | Hole Size | Plated | Hole Tolerance

2. Material: FR4
3. LAYERS - 4
4. Thickness: 2.0 mm
5. Min Track/Spacing: 5/5 mil
6. Min Hole Size: 0.71 mm
7. Solder Mask: GREEN
8. Silkscreen: White
9. Surface Finish: Immersion gold (ENIG). Thickness: 1U"
10. Via Process : Tenting vias
11. Finished Copper: 1 oz Cu
12. Inner Copper: 1 oz Cu

46 | 0.71mm | Plated
18 | 0.90mm | Plated
4 | 3.10mm | Plated
68 Total

UNLESS OTHERWISE SPECIFIED: | | NAME | DATE
DIMENSIONS ARE IN Millimeters TOLERANCES: FRACTIONAL± ANGULAR: MACH± BEND ± TWO PLACE DECIMAL ± THREE PLACE DECIMAL ± | DRAWN | | 17/03/2025

CHECKED | | | TITLE =DT_SCH_Title
ENG APPR.

THE INFORMATION CONTAINED IN THIS DRAWING IS THE SOLE PROPERTY OF . ANY REPRODUCTION IN PART OR AS A WHOLE PROPRIETARY AND CONFIDENTIAL | | | MFG APPR.

INTERPRET GEOMETRIC TOLERANCING PER: | Q.A.

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

CHECKED | | | TITLE =DT_SCH_Title
ENG APPR.

THE INFORMATION CONTAINED IN THIS DRAWING IS THE SOLE PROPERTY OF | | | MFG APPR.

INTERPRET GEOMETRIC TOLERANCING PER: | Q.A.

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

CHECKED | | | TITLE =DT_SCH_Title
ENG APPR.

THE INFORMATION CONTAINED IN THIS DRAWING IS THE SOLE PROPERTY OF | | | MFG APPR.

INTERPRET GEOMETRIC TOLERANCING PER: | Q.A.

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

CHECKED | | | TITLE =DT_SCH_Title
ENG APPR.

THE INFORMATION CONTAINED IN THIS DRAWING IS THE SOLE PROPERTY OF | | | MFG APPR.

INTERPRET GEOMETRIC TOLERANCING PER: | Q.A.

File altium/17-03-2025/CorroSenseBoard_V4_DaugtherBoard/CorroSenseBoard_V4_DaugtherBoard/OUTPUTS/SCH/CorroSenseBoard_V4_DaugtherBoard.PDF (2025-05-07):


Lock-in Daugther Board


C203 4.7uF | *SHDN2 PGND


GND

GND | CH A+ 2

C307 | 1IN+ 3 VDD+ 4

RA 16
RB 14 RF 15

1IN+ 3 | | GND

C315 +5V | | VDD+ 4 | -5V

2IN+ 5
2IN– 6

RINB 17 CH B+ 18

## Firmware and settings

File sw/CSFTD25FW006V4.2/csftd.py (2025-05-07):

from pickle import FALSE
from enum import Enum
import serial
import time

class SysStatusStates(Enum):
    ERROR = 0
    OK = 1
    BUSY = 2
    TIMEOUT = 3
    INVALID = 4
    BUS_BUSY = 5

class Csftd:

    def __init__(self):
        self.serialPort = serial.Serial()
        self.serialPort.timeout = 0
        self.serialPort.baudrate = 115200
        self.serialPort.port=''

    def connect(self, _port, _baudrate):
        if not self.is_connected():
            self.serialPort.port = _port
            self.serialPort.baudrate = _baudrate
            self.serialPort.open()

    def disconnect(self):
        if self.is_connected():
            self.serialPort.close()

    def is_connected(self):
        return self.serialPort.is_open

    def send_request_no_payload(self, cmdid):

        if self.is_connected():
            datagram = bytearray([35])
            datagram.append(0)
            datagram.append(cmdid)
            datagram.append(36)
            self.serialPort.write(datagram)
            time.sleep(1)  # Sleep for x seconds
            return True
        return False

    def send_request(self, cmdid, payload):

        if self.is_connected():
            datagram = bytearray([35])
            datagram.append(len(payload))
            datagram.append(cmdid)
            datagram += payload
            #datagram.append(payload)
            datagram.append(36)
            self.serialPort.write(datagram)
            time.sleep(0.05)  # Sleep for x seconds
            return True
        return False

    def read_response(self, length):

        if self.is_connected():
            s = bytearray(self.serialPort.read(length+4))
            if len(s) != 0:
                if s[0] == 35:
                    if s[1] == length:
                        if s[(3+length)] == 36:
                            return s[3:3+length]

                    return False

    def get_uuid(self):

        if self.is_connected():
            # Read MCU UID
            self.send_request_no_payload(1)
            uid = self.read_response(12)
            return ''.join(format(byte, '02x') for byte in uid)
        return False

    def get_mcu_adc_channel_raw(self, channel):

        if self.is_connected():
            # Prepare payload
            s = channel.to_bytes(1, "big")
            payload = bytearray(s)
            # Send request and receive answer
            self.send_request(6, payload)
            response = self.read_response(3)  # 1 byte payload
            # Parse response
            if response[0] == SysStatusStates.OK.value:
                return int.from_bytes([response[1], response[2]], "big")
            return SysStatusStates(response[0]).name  # 1 byte payload
        return False


    def get_ext_adc_channel(self, channel):

        if self.is_connected():
            # Prepare payload
            s = channel.to_bytes(1, "big")
            payload = bytearray(s)
            # Send request and receive answer
            self.send_request(18, payload)
            response = self.read_response(3)  # 1 byte payload
            # Parse response
            if response[0] == SysStatusStates.OK.value:
                return int.from_bytes([response[1], response[2]], "big")
            return SysStatusStates(response[0]).name  # 1 byte payload
        return False

    def set_dds_gain(self, value):

        if self.is_connected():
            # Prepare payload
            s = value.to_bytes(1, "big")
            payload = bytearray(s)
            # Send request and receive answer
            self.send_request(15, payload)
            response = self.read_response(1)
            return SysStatusStates(response[0]).name  # 1 byte payload
        return False

    def set_tia_gain(self, value):

        if self.is_connected():
            # Prepare payload
            s = value.to_bytes(1, "big")
            payload = bytearray(s)
            # Send request and receive answer
            self.send_request(16, payload)
            response = self.read_response(1)
            return SysStatusStates(response[0]).name  # 1 byte payload
        return False

    def get_emi_mag_phase(self, frequency, dwelltime, sustain):

        if self.is_connected():
            # "Constants" - Do not change.
            sustaintrue = 90  # 90=TRUE, 165=FALSE
            sustainfalse = 165

            # Prepare payload
            s = frequency.to_bytes(4, "big")
            s += dwelltime.to_bytes(2, "big")
            # Disable DDS after last measurement
            if sustain:
                s += sustaintrue.to_bytes(1, "big")
            else:
                s += sustainfalse.to_bytes(1, "big")

            payload = bytearray(s)

            # Send request and receive answer
            self.send_request(30, payload)

            # Device response time depends on dwelltime
            if dwelltime != 0:
                time.sleep(0.5+dwelltime/1000)  # Sleep for x seconds

            response = self.read_response(5)  # 7 byte payload

            # Parse response
            if len(response) == 5 and response[0] == SysStatusStates.OK.value:
                # Translate response payload
                magnitude = int.from_bytes([response[1], response[2]], "big")
                phase = int.from_bytes([response[3], response[4]], "big")
                return [magnitude, phase]
            return SysStatusStates(response[0]).name
        return False

    def get_hum_temp(self):

        if self.is_connected():
            # Send request and receive answer
            self.send_request_no_payload(19)
            response = self.read_response(5)  # 1 byte payload
            # Parse response
            if response[0] == SysStatusStates.OK.value:
                ambienttemp = int.from_bytes([response[1], response[2]], "big")
                relhumidity = int.from_bytes([response[3], response[4]], "big")
                return [ambienttemp, relhumidity]
            return SysStatusStates(response[0]).name  # 1 byte payload
        return False

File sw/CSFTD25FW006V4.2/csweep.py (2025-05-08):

from pickle import FALSE

import serial
import time
import math
from csftd import Csftd
import matplotlib.pyplot as plt
import numpy as np
import os
import csv

DWELL_TIME = 2   # ms
# Emi sweep parameters
FREQ_BEGIN = 200*10000  # 20 kHz
FREQ_END = 271*10000  # 500 kHz

FREQ_BEGIN = 200*10000  # 20 kHz
FREQ_END = 350*10000  # 500 kHz
STEPS = 100  # points between begin and end freq's

DDS_GAIN = 10  # 0-255
TIA_GAIN = 0  # 0-255 0 is maximum gain, 255 is minimum gain

output_dir = r"C:\CorroSenseBoardV4\measurements\TIA test"





csdev = Csftd()

# Open connection
csdev.connect('COM4', 115200)

for tia in range(0, 10, 1):
    TIA_GAIN = tia  # 0-255 0 is maximum gain, 255 is minimum gain

    if csdev.is_connected():
        print('Device connected')

        # Read MCU UID
        print('Device UID: ' + csdev.get_uuid())

        # Read MCU internal voltage reference
        print('MCU VREF INT: ' + str(csdev.get_mcu_adc_channel_raw(0)) + ' RAW')

        # Read MCU internal temperature
        print('MCU TEMPERATURE: ' + str(csdev.get_mcu_adc_channel_raw(1)) + ' RAW')

        # Set DDS gain
        print('DDS gain: ' + csdev.set_dds_gain(DDS_GAIN))

        # Set TIA gain
        print('TIA gain: ' + csdev.set_tia_gain(TIA_GAIN))

        # Get ADS1115 CHANNEL_AIN0_GND
        print('ADS1115 AIN0_GND: ' + str(csdev.get_ext_adc_channel(4)) + ' RAW')

        # Get ADS1115 CHANNEL_AIN1_GND
        print('ADS1115 AIN1_GND: ' + str(csdev.get_ext_adc_channel(5)) + ' RAW')

        # Get ADS1115 CHANNEL_AIN2_GND
        print('ADS1115 AIN2_GND: ' + str(csdev.get_ext_adc_channel(6)) + ' RAW')

        # Get ADS1115 CHANNEL_AIN3_GND
        print('ADS1115 AIN3_GND: ' + str(csdev.get_ext_adc_channel(7)) + ' RAW')

        # Emi sweep parameters
        freqbegin = FREQ_BEGIN  # 20 kHz
        freqend = FREQ_END  # 500 kHz
        steps = STEPS  # points between begin and end freq's
        dwelltime = DWELL_TIME   # ms

        # Calc step size
        stepsize = int(round((freqend - freqbegin) / (steps - 1), 0))
        freq = freqbegin  # First sweep frequency

        # Arrays for sweep data
        x = []
        #vout = []
        mag = []
        phi = []

        # Begin sweep
        print('\n------Sweep start------\n')

        htresult = csdev.get_hum_temp()
        print('HIH6121 Temperature: '+ str(htresult[0]/100) + ' °C  Humidity: ' + str(htresult[1]/100) + ' RH\n')

        #print('Index ; Frequency [Hz] ; Vo ; Magnitude ; Phase [°]')
        print('Index ; Frequency [Hz] ; Magnitude ; Phase [°]')

        test = csdev.get_emi_mag_phase(freq, dwelltime, False)
        test = csdev.get_emi_mag_phase(freq, dwelltime, True)

        test = csdev.get_emi_mag_phase(freq, dwelltime, False)
        test = csdev.get_emi_mag_phase(freq, dwelltime, True)



        # Loop through frequencies
        for i in range(steps):

            if i == (steps - 1):
                result = csdev.get_emi_mag_phase(freq, dwelltime, False)
            else:
                result = csdev.get_emi_mag_phase(freq, dwelltime, True)

            # Convert measurements to application units
            #phi_degrees = math.degrees(2 * math.pi * (phase / vdd))
            # Mag = (Rf*Vin)./TIA_VOUT;
            #mag_ = (1000 * vo) / amp
            if result[0] != 0:
                #mag_ = (1000 * 1) / result[0]
                mag_ = result[0]
            else:
                mag_ = 0

            if result[1] != 0:
                #phi_degrees = math.degrees(2 * math.pi * (result[1] / 2.8))
                phi_degrees = result[1]
            else:
                phi_degrees = 0

            # Store data to arrays for plotting
            x.append(int(freq / 10))
            #vout.append(vo)
            mag.append(mag_)
            phi.append(phi_degrees)

            # Output data to console
            """print(str(i) + ' ; ' + str(freq / 10) + ' ; ' + str(round(vo, 3)) + ' ; ' + str(round(mag_, 3)) + ' ; ' + str(
                round(phi_degrees, 2)))"""

            print(str(i) + ' ; ' + str(freq / 10) + ' ; ' + str(round(mag_, 3)) + ' ; ' + str(
                round(phi_degrees, 2)))

            # Increment frequency
            freq += stepsize
        else:
            print("\n------Sweep done------\n")



        # # Plot data
        # plt.subplot(2, 1, 1)
        # plt.plot(x, mag)
        # plt.xlabel("Frequency [Hz]")
        # plt.ylabel("Magnitude")

        # plt.subplot(2, 1, 2)
        # plt.plot(x, phi)
        # plt.xlabel("Frequency [Hz]")
        # plt.ylabel("Phase [°]")
        # plt.show()

        
        # Output directory
        os.makedirs(output_dir, exist_ok=True)

        # Create a descriptive filename
        base_filename = f"sweep_{FREQ_BEGIN/10000}_{FREQ_END/10000}_{stepsize}res_{DWELL_TIME}ms_DDS{DDS_GAIN}_TIA{TIA_GAIN}"

        # Plot and save figure
        plt.figure(figsize=(10, 6))
        plt.subplot(2, 1, 1)
        plt.plot(x, mag)
        plt.xlabel("Frequency [Hz]")
        plt.ylabel("Magnitude")

        plt.subplot(2, 1, 2)
        plt.plot(x, phi)
        plt.xlabel("Frequency [Hz]")
        plt.ylabel("Phase [°]")

        plot_path = os.path.join(output_dir, f"{base_filename}.png")
        plt.tight_layout()
        plt.savefig(plot_path)
        #plt.show()

        plt.close()  # Closes the current figure

        # Save data as CSV
        csv_path = os.path.join(output_dir, f"{base_filename}.csv")
        with open(csv_path, mode='w', newline='') as file:
            writer = csv.writer(file)
            writer.writerow(["Frequency [Hz]", "Magnitude", "Phase [°]"])
            for freq, m, p in zip(x, mag, phi):
                writer.writerow([freq, m, p])

        print(f"Saving plot to: {plot_path}")
        print(f"Saving CSV to: {csv_path}")

    else:
        print('Connection error')


# Close connection
csdev.disconnect()
print('Device disconnected')

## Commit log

2025-05-07 Created repo added files
    [473460001.PcbLib, 473460001.SchLib, 5Vsupply.SchDoc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]
2025-05-07 Added daugtherboard schematic
2025-05-07 Board is running and working
    [TRACE01MAGPHASE.CSV, TRACE01MAGPHASE.xlsx, TRACE01XY.CSV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]
2025-05-08 Added some readme and did some measurements
    [sweep_100.0_271.0_2140res_2ms_DDS10_TIA1.csv, sweep_100.0_271.0_2140res_2ms_DDS10_TIA2.csv, sweep_100.0_271.0_2140res_2ms_DDS10_TIA3.csv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]
